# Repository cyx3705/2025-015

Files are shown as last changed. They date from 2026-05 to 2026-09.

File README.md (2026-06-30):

# 2025-015-弹簧测试机械

> 液压与气动 PLC 综合实训装置，面向机电、自动化专业教学实操设备，用于电 - 气 - 液 - 机械联动 PLC 编程实训教学

## 项目效果图
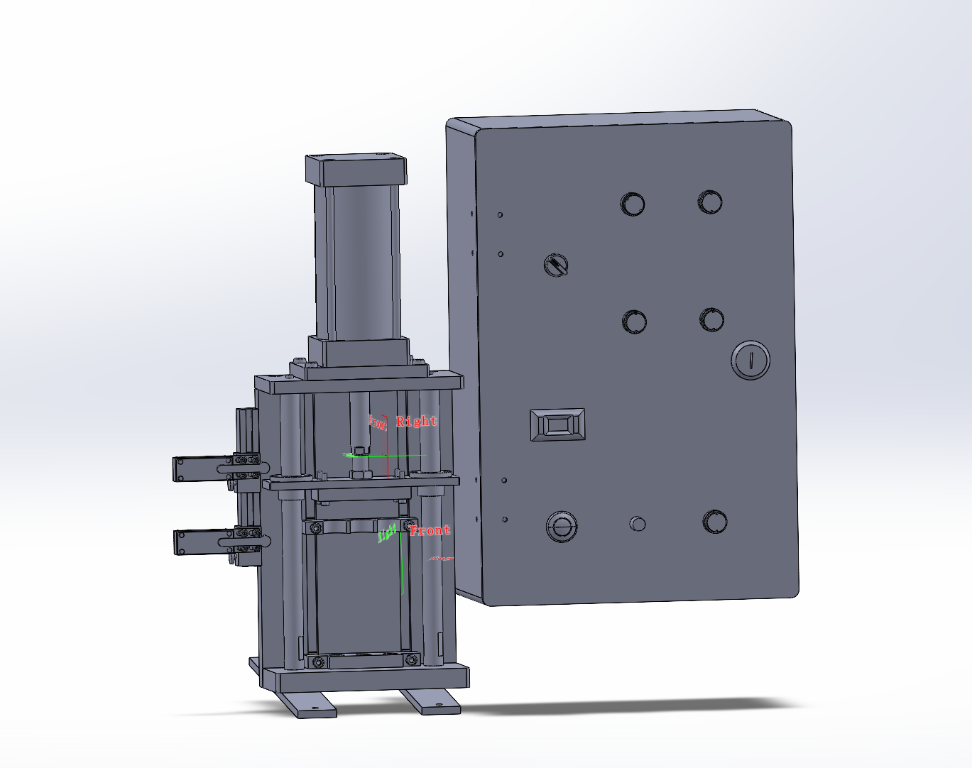
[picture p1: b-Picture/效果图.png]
效果图


## 项目内容

1. **项目定位**
本设备为宁波工程学院机器人学院自研实训设备，是机电、自动化专业入门实操训练平台，依托三菱 PLC 实现气动 / 液压部件动作控制，直观展示电、气、液、机械一体化联动逻辑，作为工业自动化课程配套实践教具。
2. **硬件组成**

- 操作控制面板：急停按钮、上升 / 下降 / 启动 / 停止功能按键、手动 / 自动模式旋钮、电源开关、24V 开关电源；
- 控制核心：三菱 PLC 控制器，负责存储、执行控制逻辑程序；
- 配套电气元件：继电器、端子排、行程传感器、电磁阀执行机构；
- 配套气动液压执行单元：升降气缸、液压气动管路组件。

3. **控制系统说明**

- 硬件接线：外部按钮、急停、行程传感器信号接入 PLC 输入端子，PLC 输出驱动继电器控制气缸升降执行动作；
- 控制逻辑：包含手动单步控制、自动循环升降两套模式，搭配上下限位行程开关实现气缸限位保护；
- 配套资料：完整电气原理图、I/O 梯形图程序、端子接线对照表、整机装配实物图。

4. **实训教学功能**

- 基础实操：电气线路接线、气动液压回路搭建、PLC 硬件接线规范练习；
- 编程实训：三菱梯形图逻辑编写、手动 / 自动模式切换控制、限位互锁程序设计；
- 综合训练：电 - 气联动系统联调、设备故障排查、整机自动化流程调试；
- 课程价值：打通自动化理论与工程实操，掌握元件装配、程序设计、系统联调完整工程流程。

5. **配套文档资源**

- 《液压与气动 PLC 综合实训装置说明书.docx》：整机结构、部件功能、操作规范、实训总结；
- 电气图纸：主回路电气原理图、PLC 控制梯形图、I/O 端子接线对照表；
- 实物素材：控制面板、箱内 PLC 布线、元器件装配实拍图。

## 保留内容
- 本模板项目介绍：此为最初的准备的项目模板
    每个分支项目都会由他去继承
- 作者：Pinavia - 2025

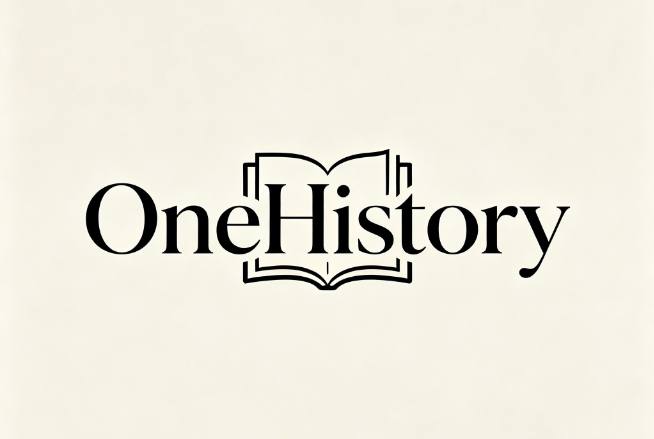
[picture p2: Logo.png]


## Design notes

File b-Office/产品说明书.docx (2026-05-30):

液压与气动 PLC 综合实训装置说明书

一、设备定位：

这是专为机电、自动化专业新手设计的实操训练设备，能帮你从 “看不懂机器” 到 “亲手指挥机器干活”—— 通过 PLC 编程控制气动 / 液压部件动作，直观理解 “电 - 气 - 液- 机械” 的联动逻辑，是工业自动化学习的 “入门实践工具”。控制装置外装如下图

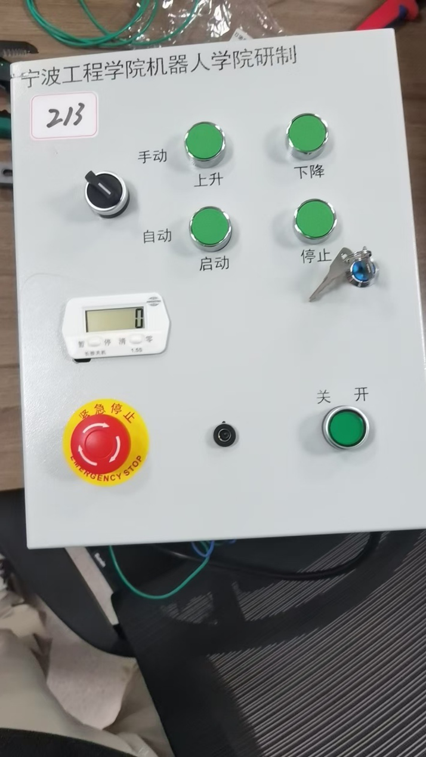
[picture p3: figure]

二、设备部件全解以及原理基础

（一）控制单元（设备左侧：“大脑+控制中枢”）

名称 | 外观 | 功能 | 如何操作
急停按钮 | 箱体外部红色旋转按钮，最为显眼 | 紧急停止所有动作，设备断电 | 按下去后需顺时针旋转复位
功能按钮 | 箱体外部上方绿色小按钮（急停旁） | 手动发送 “上升/ 下降 / 自动/停止” 指令 | 按动时轻按，避免用力过猛损坏
三菱 PLC 控制器 | 箱体内部中间 | 设备 “大脑”，存储 / 执行你的控制程序 | 编程前需连接电脑，禁止带电拔线
开关电源 | 箱体外部右下方 | 输出 24V 安全电压，给电气部件供电 | 控制执行单位的电源

（二）控制部件电气原理图如下

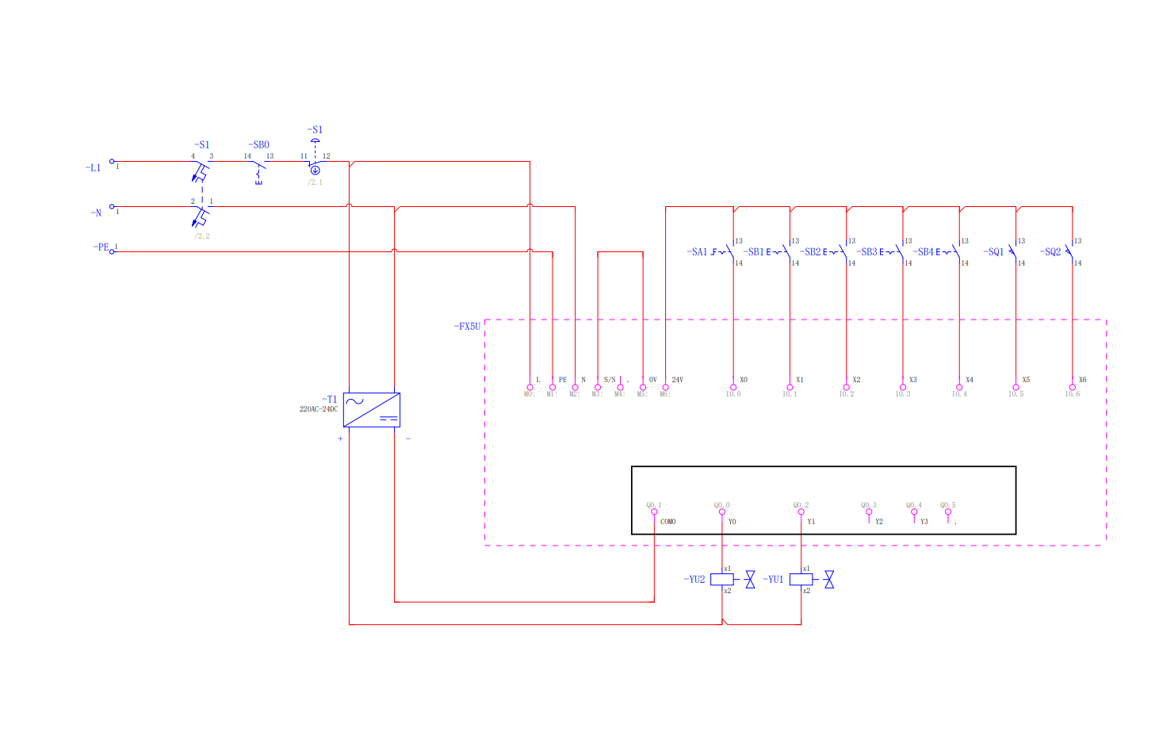
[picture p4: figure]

其中S1为主闸，SA1为急停开关，SB1,SB2,SB3,SB4为功能按钮。当左侧的急停、按钮、传感器等元件动作时，信号通过端子排传到 - P130 - 模块的输入口；模块根据程序判断后，从输出口发出信号，驱动右侧的继电器 / 接触器，最终控制设备的运行、停止等动作。以下为梯形图

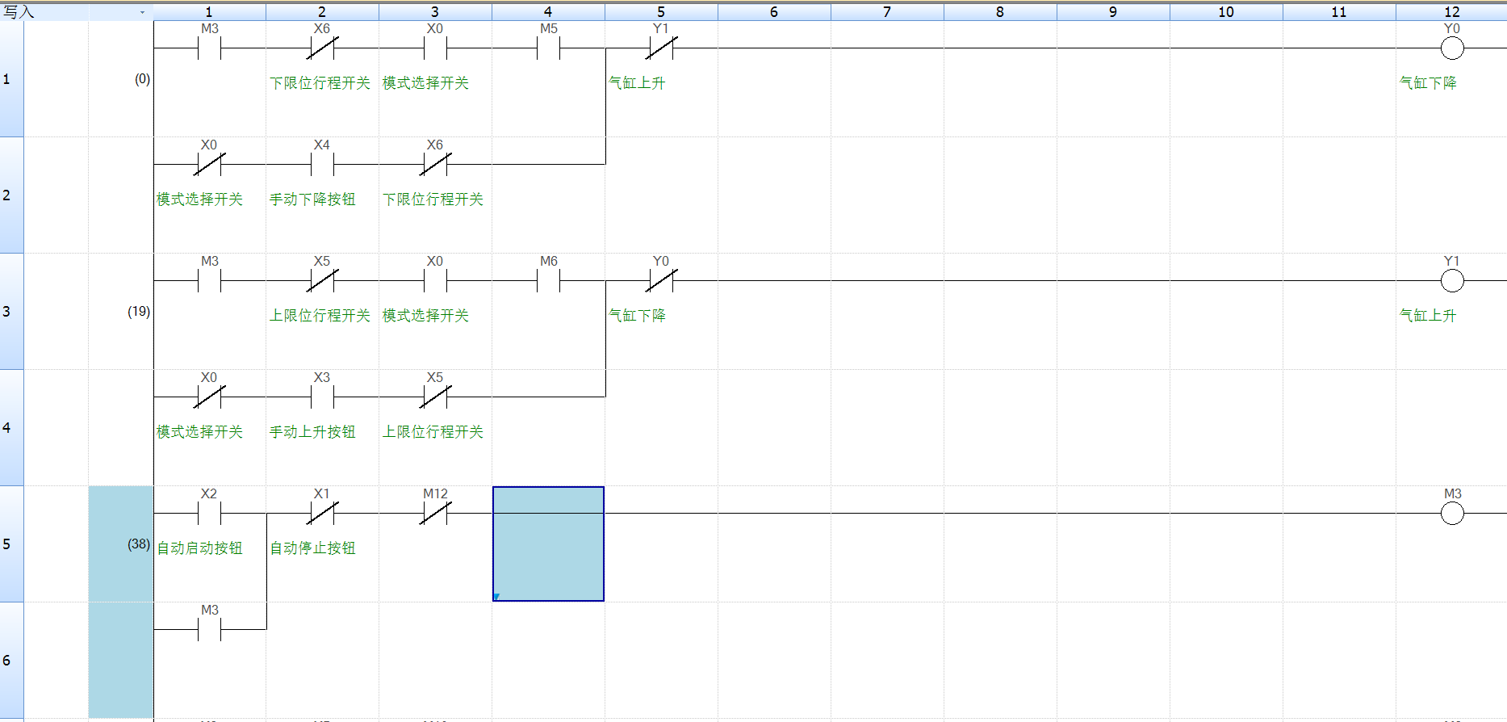
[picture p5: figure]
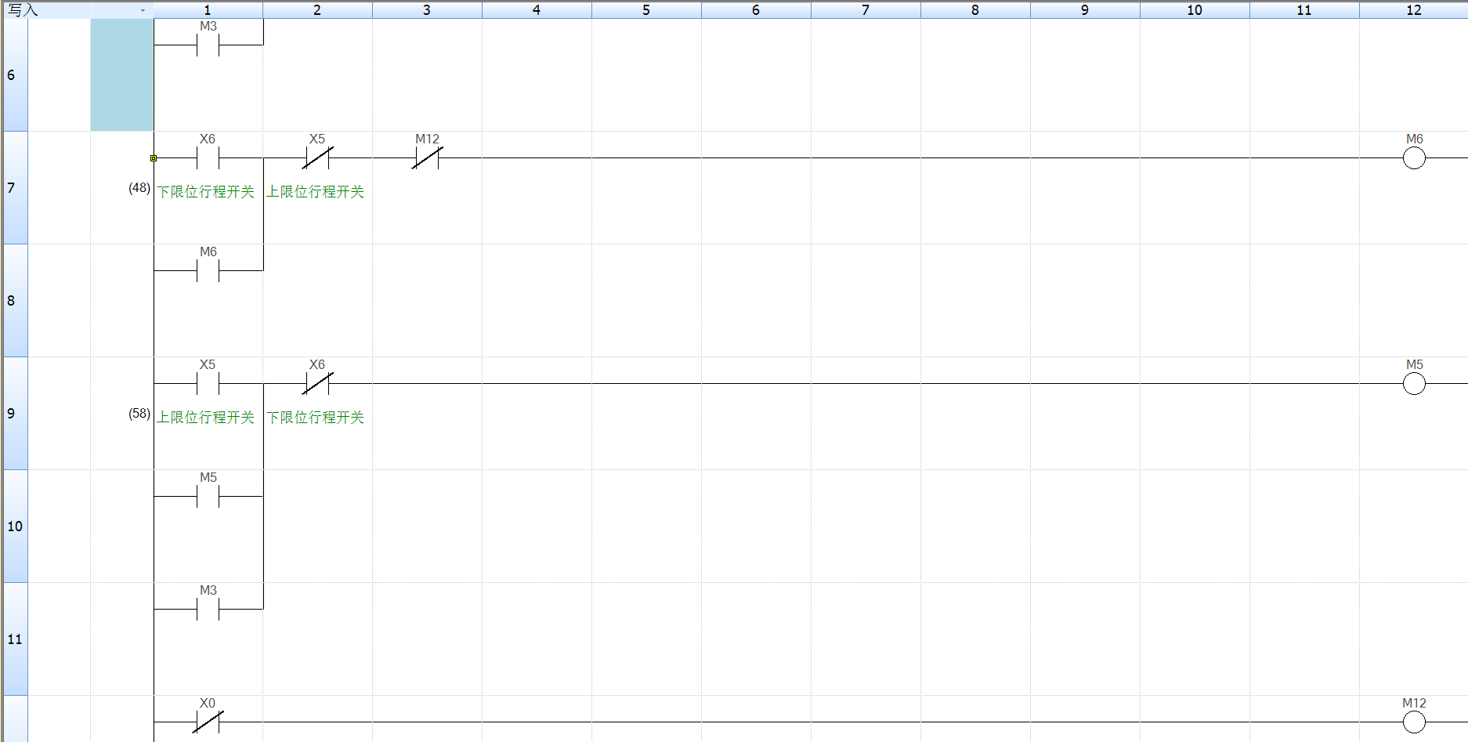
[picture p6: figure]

1控制部分的梯形图

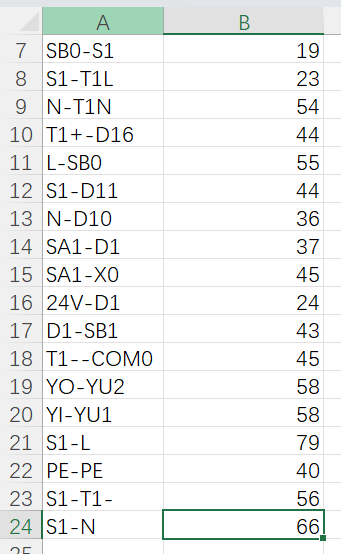
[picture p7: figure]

以下为详细接线表

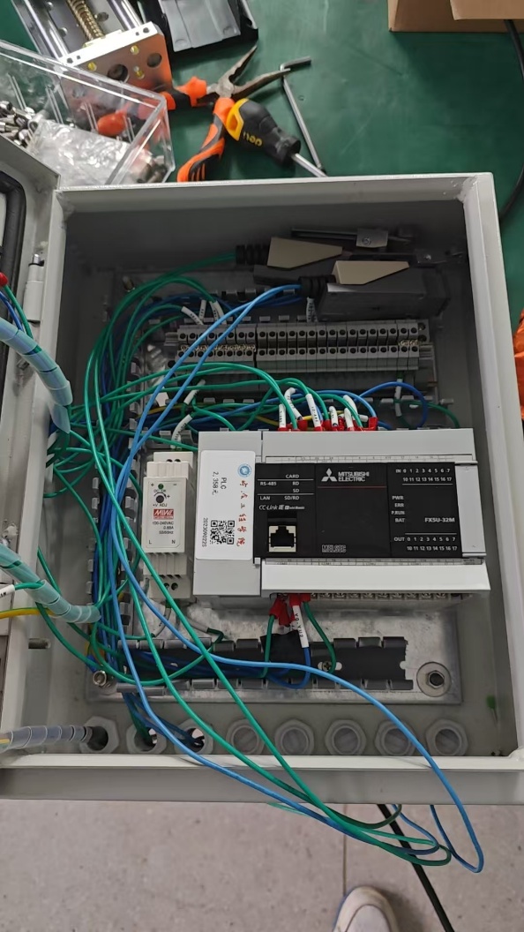
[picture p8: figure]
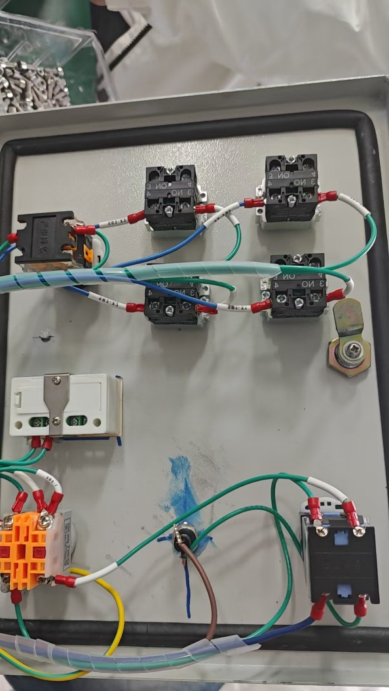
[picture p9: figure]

（三）最后的总装实物图

三、课程小结

本次液压与气动PLC综合实训，以实操为核心载体，有效打通了理论与工程应用的衔接。通过实训装置的实操演练，不仅夯实了专业基础，将分散的液压气动元件知识、PLC编程逻辑深度融合，清晰掌握了回路搭建、程序设计与系统联动的完整流程，更实现了从理论学习者到动手实践者的转变。

实训中，熟练掌握了元件组装、管路连接、PLC编程及常见故障排查等核心技能，同时培养了工程化思维与规范操作意识。此次实训不仅提升了专业实操能力，更构建起完整的知识应用体系，为后续专业学习和工程实践奠定了坚实基础。

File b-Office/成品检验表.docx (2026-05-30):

产品名称： 生产批次 ：

型号规格： 检验日期： 年 月 日

生产单位： 检验人员：

检验类型 □ 出厂检验 □ 型式检验 □ 复检 □ 其他：______ 抽样数量 （全检填 “全检”）

序号 | 检验项目 | 检验要求 | 检验方法 | 检验工具 | 检验结果（合格/不合格/无此项） | 备注
1 | 外观及安装检查 | 1. 设备整体无变形、破损，表面无明显划痕、污渍；2. 各元器件（气缸、电磁阀、行程开关、按钮、保险盒、PLC等）安装牢固、位置准确，固定螺栓无松动；3. 线路布置规整，绑扎牢固，标识清晰，无交叉缠绕、破损裸露现象；4. 气管连接密封良好，无松动、老化迹象 | 目视检查设备外观，手动检查元器件固定情况，梳理线路和气管布置 | 扳手、螺丝刀（辅助检查螺栓紧固性）
2 | 电气系统基础性能 | 1. 电源适配正常，接入24V直流电源后，设备无短路、漏电现象；2. 保险盒选型合理，保险管规格符合设计要求，能正常起到过载保护作用；3. 各电气元器件接线正确，无接错、虚接情况 | 1. 接入24V电源，用测电工具检测电源输出及设备供电情况；2. 检查保险盒及保险管规格，模拟轻微过载场景验证保护功能；3. 对照电气原理图核查接线准确性 | 万用表、测电笔、电源适配器（24V）
3 | 气动系统性能 | 1. 压缩空气压力稳定在0.6MPa，无泄漏；2. 气缸推力不大于4500N，运行平稳，无卡顿、异常异响；3. 三位五通电磁阀动作灵敏，能准确控制气缸换向 | 1. 接入压缩空气，调节压力至0.6MPa，保持10分钟，观察压力表变化及气管、接口处是否漏气；2. 启动设备使气缸运行，用测力计测量气缸推力；3. 分别控制电磁阀YV1、YV2线圈通电，观察气缸换向是否准确 | 压力表、测力计、肥皂水（检测漏气）
4 | 常规电气控制功能（方案一） | 1. 模式切换正常：通过选择开关切换手动/自动模式，切换后对应模式按钮生效，另一模式按钮失效；2. 手动模式：按下“上升”“下降”按钮，滑块准确动作，松开按钮滑块保持当前位置；3. 自动模式：按下“启动”按钮，滑块下行，触发下限位行程开关（SQ2）后换向上行；触发上限位行程开关（SQ1）后换向下行，实现往复循环；按下“停止”按钮，设备立即停止，滑块保持位置 | 1. 操作模式选择开关，分别在两种模式下测试各控制按钮功能；2. 自动模式下启动设备，观察滑块往复运动及行程开关触发后的换向情况，测试停止按钮功能 | 秒表（辅助观察循环稳定性） | | 无常规电气控制方案时填“无此项”
5 | PLC控制功能（方案二） | 1. 与常规电气控制功能要求一致（模式切换、手动/自动模式动作正常）；2. PLC输入输出信号准确，与I/O地址分配表完全匹配；3. 梯形图程序运行稳定，无程序错误、动作紊乱现象 | 1. 同常规电气控制功能测试方法；2. 用PLC编程软件连接设备，监控输入输出信号状态，对照I/O地址分配表核查；3. 连续运行自动模式30分钟，观察程序运行稳定性 | PLC编程软件、电脑（连接PLC）、秒表 | | 无PLC控制方案时填“无此项”
6 | 行程开关功能 | SQ1（上限位）、SQ2（下限位）安装位置准确，滑块运动至极限位置时能可靠触发，触发后立即控制气缸换向，无延迟、误触发情况 | 启动自动模式，观察滑块运行至上下极限位置时行程开关的触发状态及气缸换向响应；手动推动滑块触碰行程开关，验证触发可靠性 | 直尺（辅助测量行程开关安装位置）
7 | 安全性能 | 1. 设备运行过程中无漏电、异响、过热等安全隐患；2. 停止按钮反应灵敏，紧急情况下能快速切断控制信号，保障设备和人员安全 | 1. 设备连续运行1小时，用红外测温仪检测关键元器件（PLC、电磁阀、电源接口）温度，用测电笔检测设备外壳是否漏电；2. 多次测试停止按钮，验证紧急停止功能 | 红外测温仪、测电笔
8 | 附属资料核查 | 电气原理图（标注电线规格）、电气开线表、BOM清单、产品说明书、PLC梯形图、I/O地址分配表等资料完整、准确，与成品实际情况一致 | 对照成品设备，逐一核查各项附属资料的完整性和准确性 | 相关设计资料（电气原理图、BOM清单等）
9 | 其他专项要求 | 根据项目设计补充的其他技术要求（如运行噪音、循环稳定性等） | 按补充技术要求对应的测试方法执行 | 对应专项测试工具 | | 无专项要求时填“无此项”

检验结论： □ 合格（所有检验项目均符合要求） □ 不合格（存在不符合项，详见备注） □ 整改后合格（不符合项已整改并验证通过）

不合格项整改要求 ：1. 不符合项描述：

2. 整改期限： 年 月 日

3. 整改措施：

整改后检验结果： □ 合格 □ 仍不合格

审核人员签字： 日期： 年 月 日

备注 （其他需要说明的事项）：

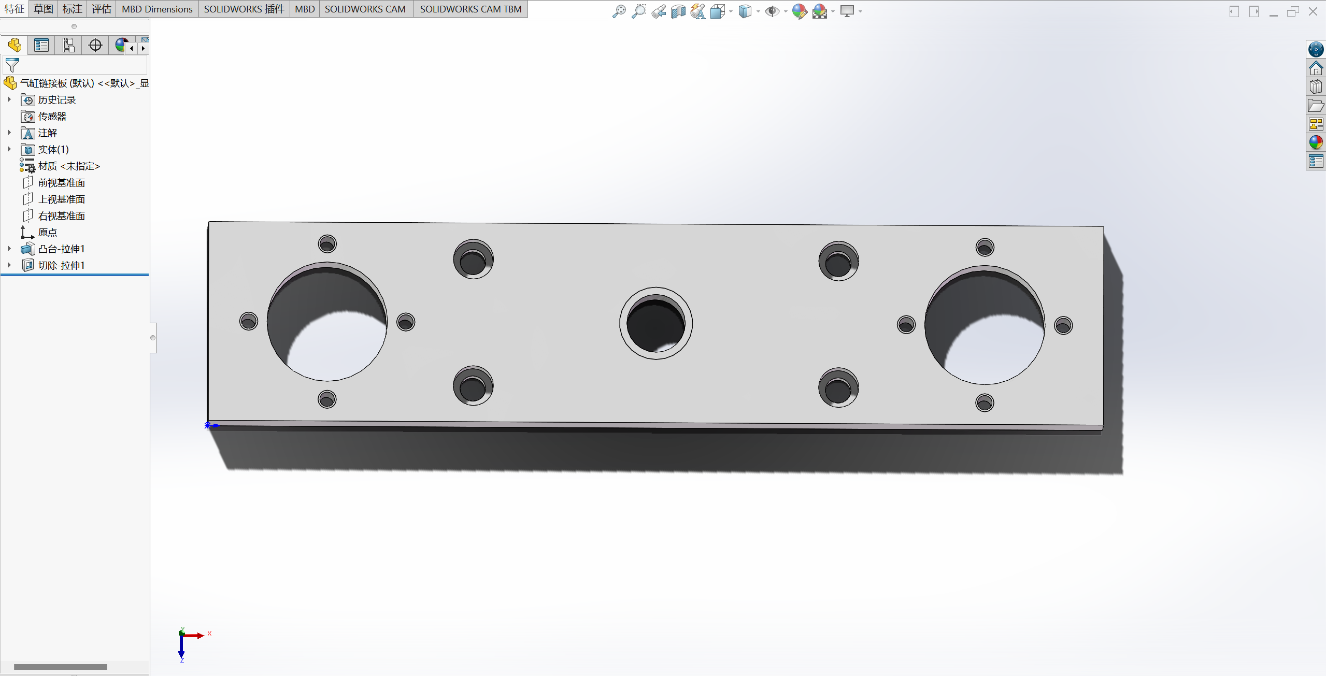
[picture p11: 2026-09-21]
b-Picture/第四次作业图片记录 (1).png

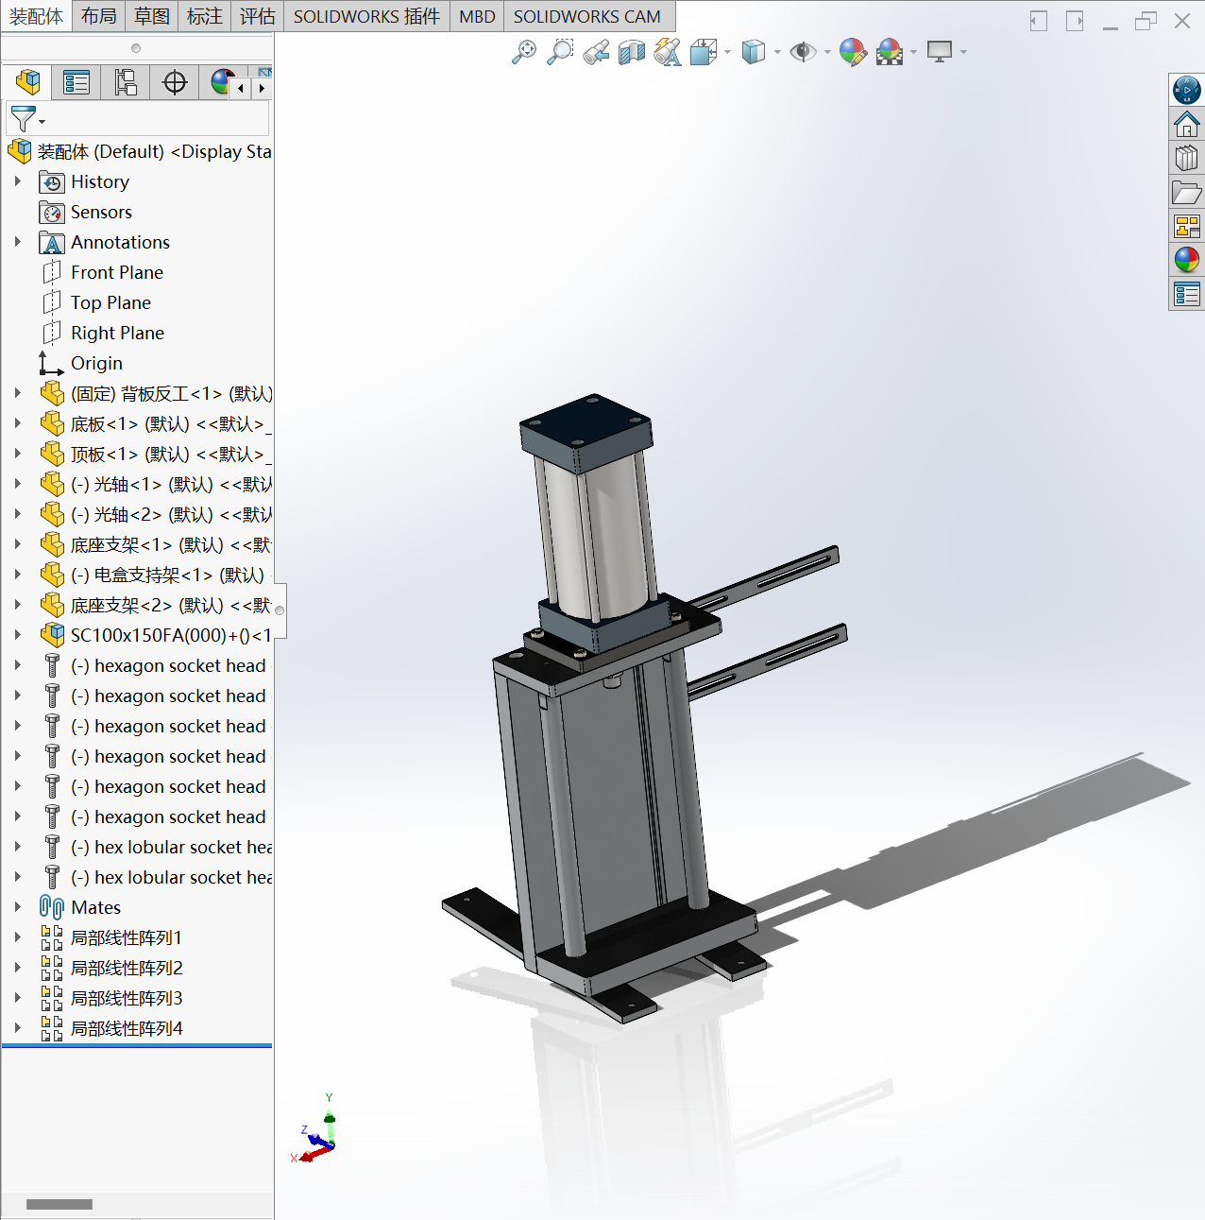
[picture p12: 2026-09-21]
b-Picture/第三次作业图片记录 (6).png

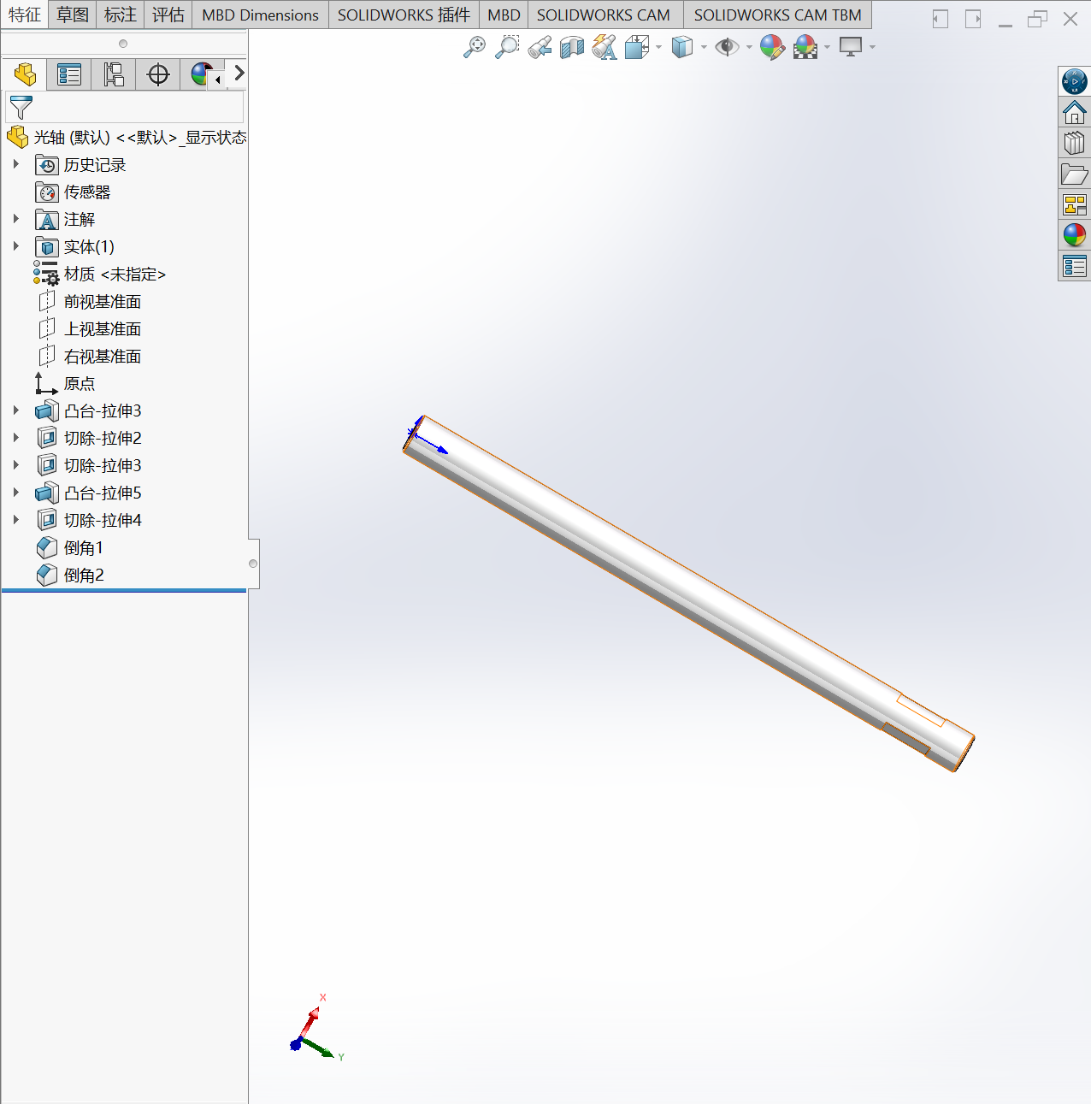
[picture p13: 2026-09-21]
b-Picture/第三次作业图片记录 (3).png

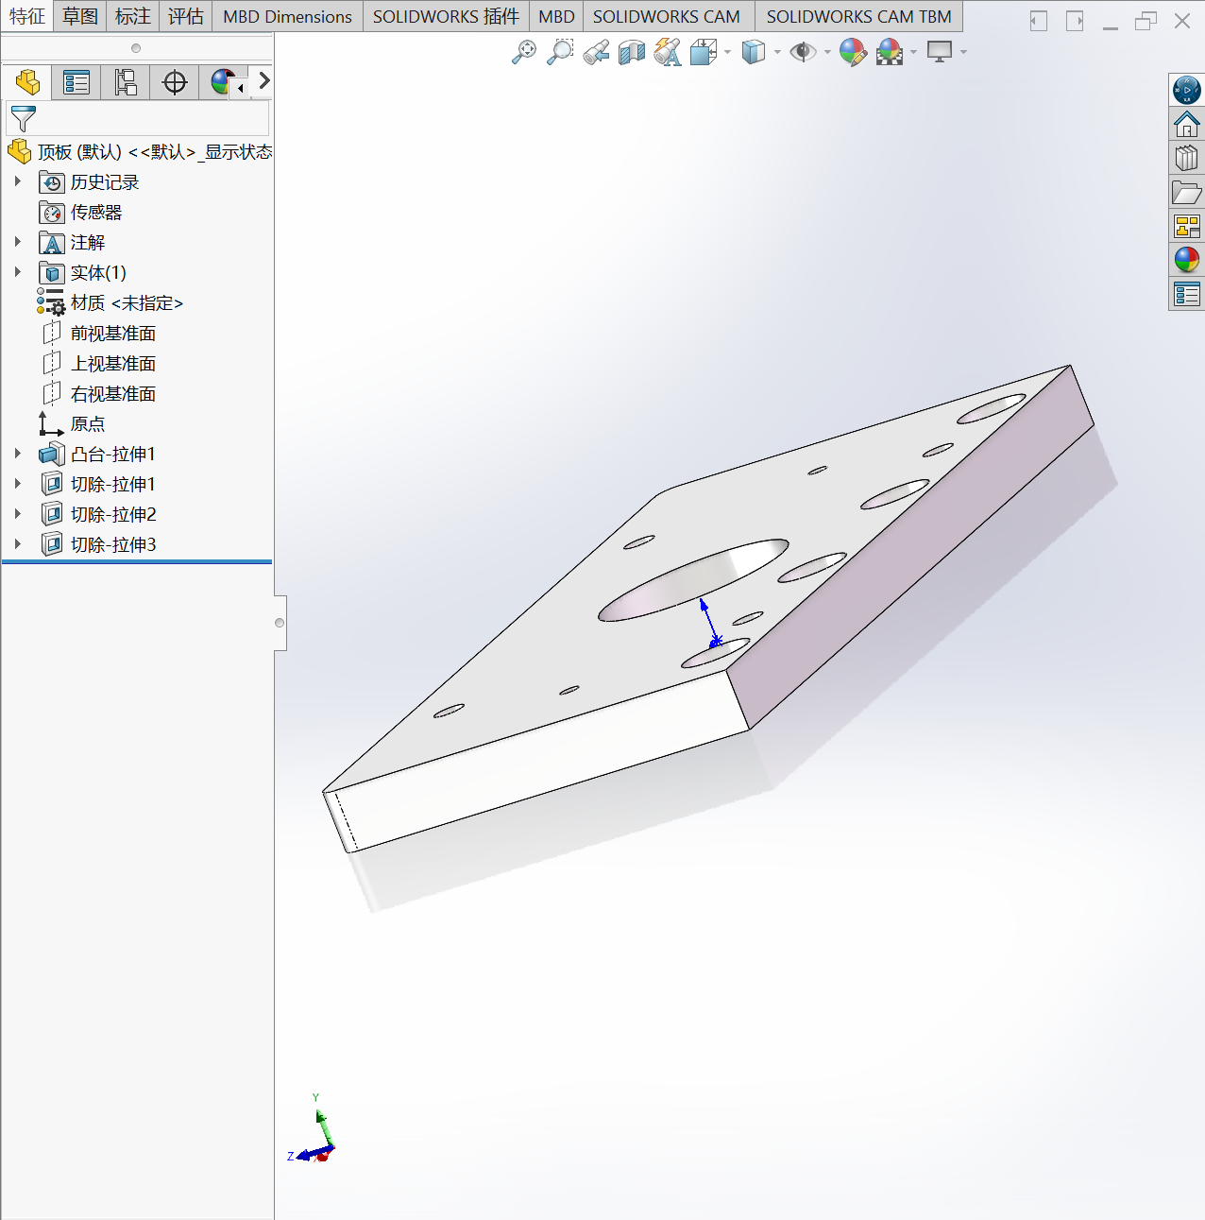
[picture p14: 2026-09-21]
b-Picture/第三次作业图片记录 (5).png

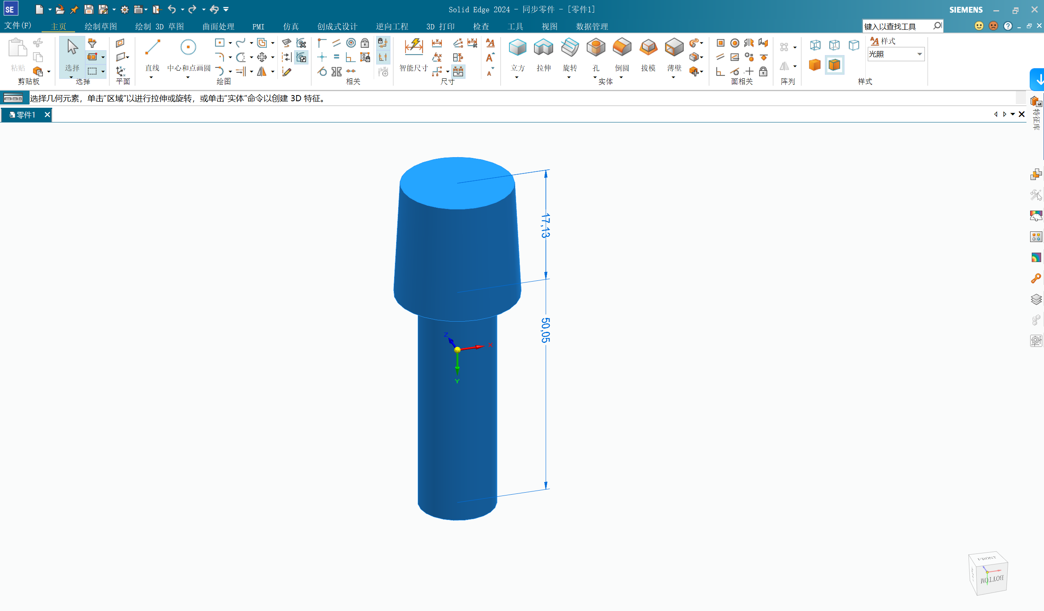
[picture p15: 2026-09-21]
b-Picture/第五次作业图片记录 (3).png

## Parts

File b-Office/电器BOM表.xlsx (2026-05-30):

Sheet: Revision History
Revision 版本 | Description 变更描述 | Date 变更日期 | Updated BY 变更人 | Remarks 备注

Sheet: BOM模板
Item 序号 | 名称 | 型号 | Manufacturer 制造商 | QTY 数量 | Unit 单位 | Remarks 备注
1 | SB1(上升) | NP2-EA31 | 正泰 | 1 | 个 | 绿，常开
2 | SB2(下降) | NP2-EA31 | 正泰 | 1 | 个 | 绿，常开
3 | SB3(启动) | NP2-EA31 | 正泰 | 1 | 个 | 绿，常开
4 | SB4(停止) | NP2-EA31 | 正泰 | 1 | 个 | 绿，常开
5 | 急停开关 | NP2-ES442 | 正泰 | 1 | 个 | 红，常闭
6 | 总开关 | NP2-BW1361 | 正泰 | 1 | 个 | 绿，直接式常开
7 | 旋转开关 | NP2-BD25 | 正泰 | 1 | 个 | 二位置锁定，1常开+1常闭
8 | PLC | FX5U-32M | 三菱电器 | 1 | 个
9 | 开关电源 | DR-15-24 | 明纬 | 1 | 个 | 100-240VAC 0.88A 50/60Hz
10 | 接线端子 | UK2.5B | 冠辰 | 24 | 个 | https://e.tb.cn/h.7W7ifaxQ8hWY1d1?tk=cyXVfFPszRI
11 | 电器导轨 | C45 190mm |  | 2 | 个 | https://e.tb.cn/h.7dVqYi3wGRdT4Fx?tk=GNmafFPAPV5
12 | 线槽 | 25×25×175mm | R.star | 3 | 个
13 | 电磁阀 | 4V330C10A | 亚德客 | 1 | 个 | 三位五通
14 | 行程开关 | D4V-8108SZ-N | OMRON | 2 | 个 | 5A 250VAC 0.4A 125VDC
15
16
17
18
19
20

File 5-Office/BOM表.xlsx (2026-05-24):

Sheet: Revision History
Revision 版本 | Description 变更描述 | Date 变更日期 | Updated BY 变更人 | Remarks 备注

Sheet: BOM模板
 | Product Name 成品名称 |  | DOC. Number 文件编号 |  | Rev. 版本号 |  |  | Updated BY 更新人 |  | Checked BY 审核人 |  | Approved BY 批准人
 |  |  | BOM-503TWM0203 |  | 1.00
 |  |  |  |  |  |  |  | Date 日期 |  | Date 日期 |  | Date 日期
 |  |  | Initial Date 初版日期
Item 序号 | 文档号 | Description 名称 | Specification 参数描述 | Manufacturer 制造商 |  | RoHS 有毒 元素 控制 | QTY 数量 | Unit 单位 | Substitute P/N 替代料P/N | Remarks 备注 | EPDM Auto EPDM自动导出 | Optimized 优选等级 | Unit Price 单价(RMB) | Subtotal 合计(RMB)
 |  |  |  | Model No. 型号 | Brand 品牌
1
2
3
4
5
6
7
8
9
10
11
12
13
14
15
16
17
18
19
20
 |  |  |  |  |  |  |  |  |  |  |  |  |  | Total:

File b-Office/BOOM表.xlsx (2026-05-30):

序号 | 名称 | 规格型号 | 数量 | 备注
1 | 保险丝座 |  | 1 | 无
2 | 背板反工 |  | 1
3 | 触碰开关 |  | 2
4 | 触碰开关盒 |  | 4
5 | 导轨 |  | 1
6 | 底板 |  | 1
7 | 底座支架 |  | 1
8 | 电盒支持架 |  | 1
9 | 顶板 |  | 1
10 | 刚体固定架 |  | 1
12 | 工作版 |  | 1
13 | 光轴 |  | 2
14 | 滑块 |  | 2
15 | 计数器 |  | 1
16 | 紧固螺钉 |  | 2
17 | 螺母 |  | 1
18 | 气弹簧固定版 |  | 1
19 | 气缸链接板 |  | 1
20 | 三联支架 |  | 1
21 | 锁芯 |  | 1
22 | 梯形螺母 |  | 4
23 | 铜套 |  | 2
24 | 箱盖 |  | 1
25 | 箱体 |  | 1
26 | 行程开关安专板 |  | 1
27 | 电磁阀 | 4V330C08A | 1
28 | 气缸 | SC100X150 | 1
29 | 内六角螺钉1 | M5X10 | 4
30 | 十字槽螺钉 | M3X16 | 8
31 | 内六角螺钉2 | M6X25 | 8
32 | 内六角螺钉3 | M6X10 | 8
33 | 内六角螺钉4 | M3X30 | 2
34 | 内六角螺钉5 | M8X45 | 4
35 | 内六角螺钉6 | M4X12 | 8
36 | 内六角螺钉7 | M6X35 | 4
37 | 螺母 | M6 | 4
38 | 内六角螺钉7 | M6X20 | 2
39 | 内六角螺钉8 | M6X10 | 2

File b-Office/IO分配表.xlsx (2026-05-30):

列1 | 列2 | 列3 | 列4
类型 | 元件 | 功能 | PLC地址
输入 | SA | 手动/自动选择开关（手动档） | X0
输入 | SB1 | 自动停止按钮（常开） | X1
输入 | SB2 | 自动启动按钮（常开） | X2
输入 | SB3 | 手动上升按钮（常开） | X3
输入 | SB4 | 手动下降按钮（常开） | X4
输入 | SQ1 | 上限位行程开关（常开） | X5
输入 | SQ2 | 下限位行程开关（常开） | X6
输出 | YV1 | 电磁阀线圈1，通电时气缸活塞下降 | Y0（经中间继电器KA1驱动）
输出 | YV2 | 电磁阀线圈2，通电时气缸活塞上升 | Y1（经中间继电器KA2驱动）

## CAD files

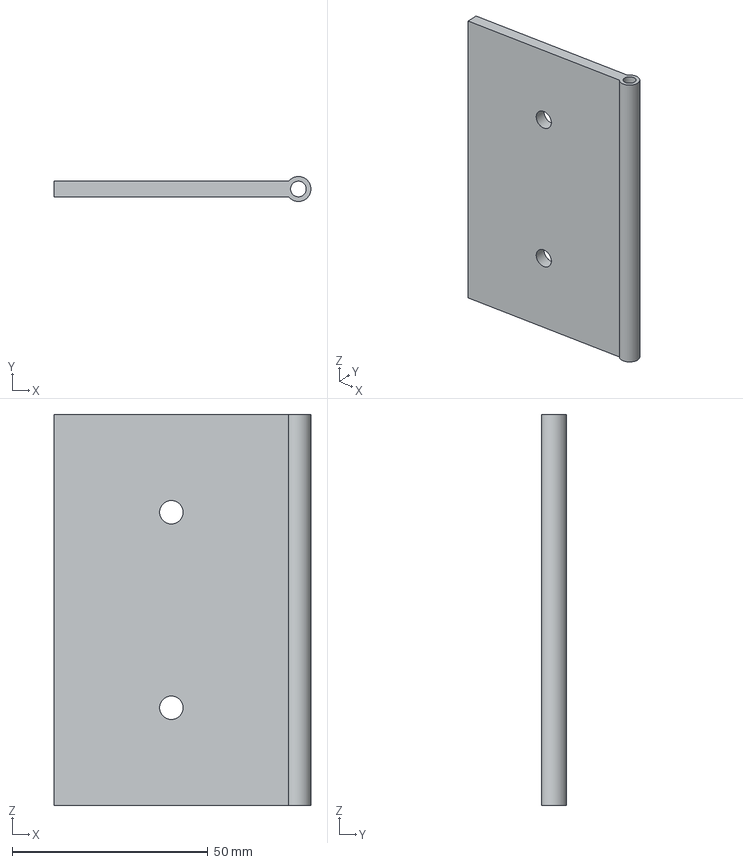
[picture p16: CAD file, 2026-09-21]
b-Module-GE/专配体/heye.stp
65.7 x 6.40 x 100.0 mm

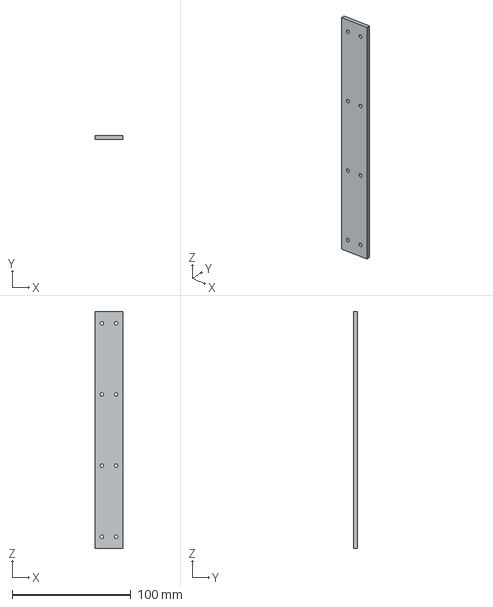
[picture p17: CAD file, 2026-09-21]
b-Module-GE/主体/右侧连接.stp
24.0 x 3.00 x 200.0 mm

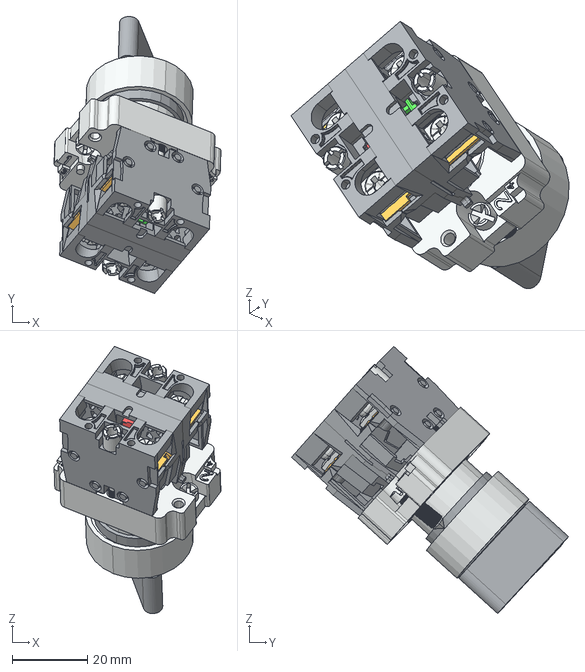
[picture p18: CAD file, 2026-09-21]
b-Module-GE/按钮/NP2-BD按钮三维模型202204.stp
44.4 x 73.7 x 71.1 mm

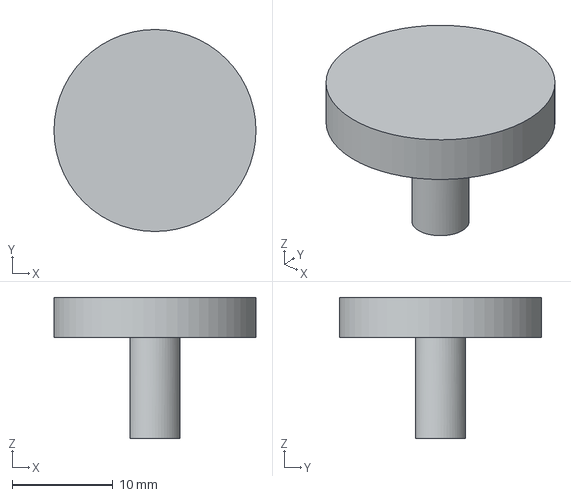
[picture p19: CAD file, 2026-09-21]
b-Module-GE/紧固螺钉.stp
20.0 x 20.0 x 14.0 mm

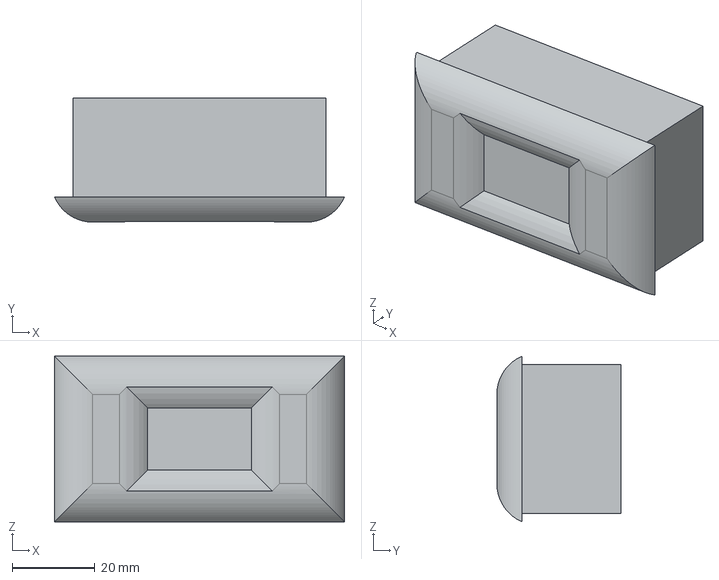
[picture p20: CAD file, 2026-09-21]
b-Module-GE/配件箱/计数器.stp
70.0 x 30.0 x 40.0 mm

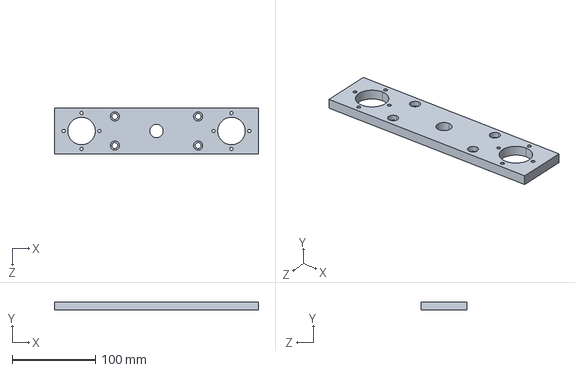
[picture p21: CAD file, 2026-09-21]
b-Module-GE/专配体/气缸链接板.STEP
245.0 x 10.0 x 55.0 mm

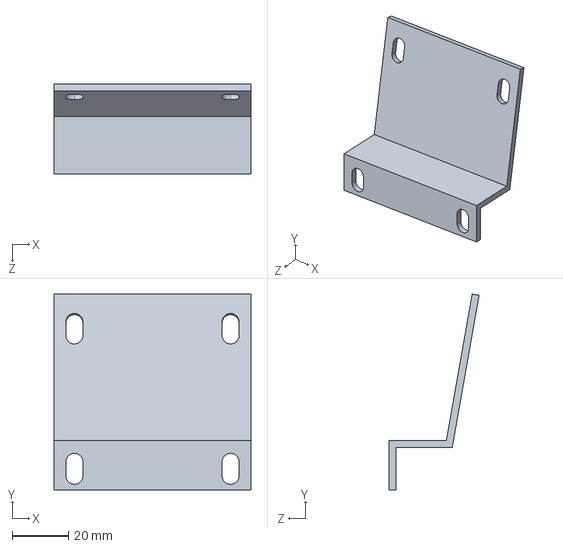
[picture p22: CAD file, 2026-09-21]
b-Module-GE/主体/三联支架.STEP
70.0 x 69.6 x 32.1 mm

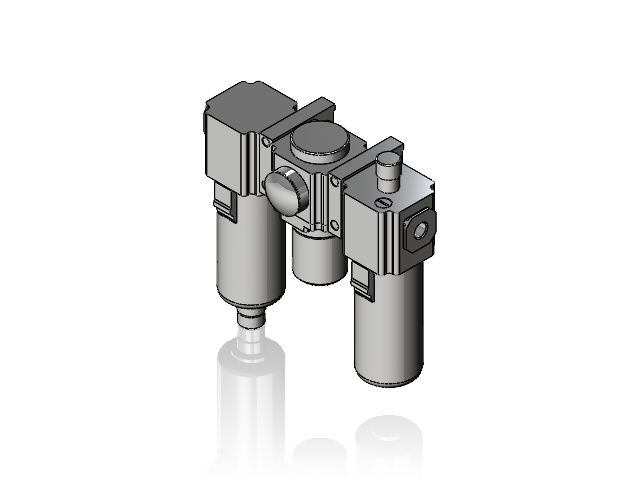
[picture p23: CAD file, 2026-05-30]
b-Module-SW/主体/气缸.SLDASM
GAF30008J
GA300L-P1 x 2
GAR30008SJ
GAL30008J

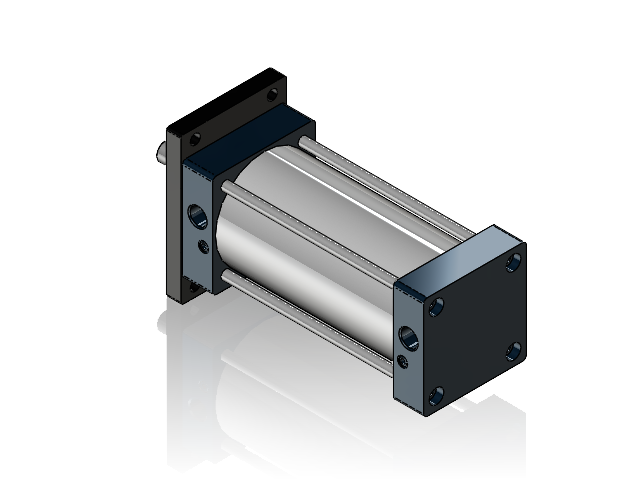
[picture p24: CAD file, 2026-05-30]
b-Module-SW/装配件/气缸/SC100x150FA(000)+()_1.sldasm
SC100X150_c
SC-100x150-FA(0)_r
SC-100-M20x1.5 - Nut
F-SC100FA(SC)
SC-100 Screw x 4

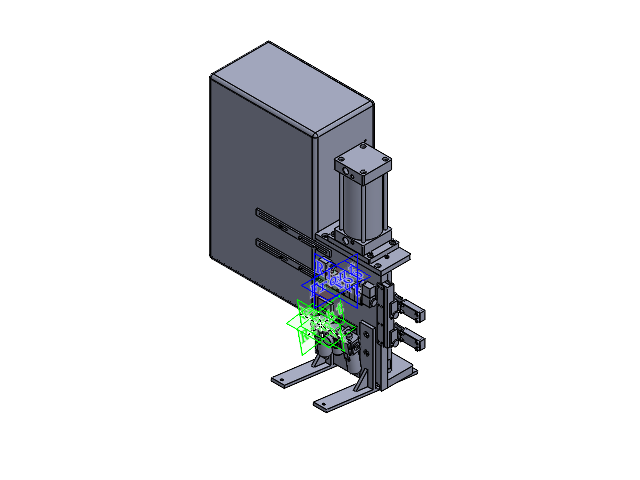
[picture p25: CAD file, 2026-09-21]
b-Module-SW/装配体2.SLDASM
背板反工
底板
顶板
光轴 x 2
底座支架 x 2
电盒支持架 x 2
hexagon socket head cap screws gb x 42
hex lobular socket head cap screws-4.8 gb x 6
行程开关安专板 x 2
箱体1
箱盖1
np2-bd按钮三维模型202204
np2-bw1按钮三维模型202204 x 5
np2-bw4按钮三维模型202204
锁芯
计数器
保险丝座
SC100X150_c
SC-100x150-FA(0)_r
F-SC100FA(SC)
螺母
lianjie
气弹簧固定版
刚体固定架
工作版
气缸链接板
铜套 x 2
梯形螺母 x 4
导轨
滑块 x 2
紧固螺钉 x 2
触碰开关盒 x 2
触碰开关.stp x 2
三联支架
4V330C-08-Valve_Body
cross recessed cheese head screws gb x 8
hex lobular socket head cap screws-8.8 gb x 12
hex nuts, style 1-grades ab gb x 4
GAF20006J
GA200L-P1 x 2
GAR20006SJ
GAL20006J

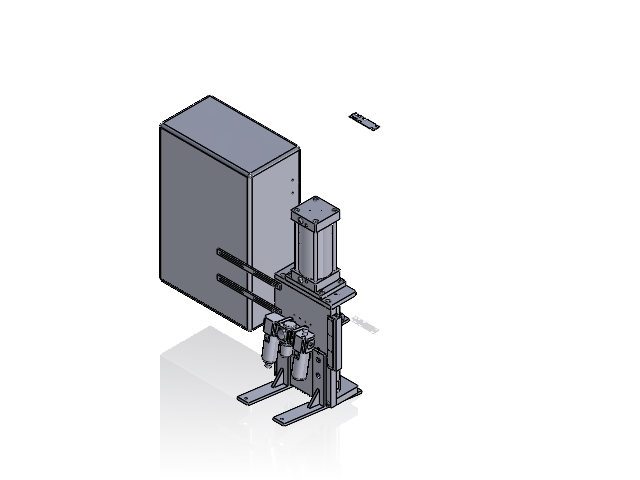
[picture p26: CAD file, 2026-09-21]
b-Module-SW/装配体.SLDASM
背板反工
底板
顶板
光轴 x 2
底座支架 x 2
电盒支持架 x 2
hexagon socket head cap screws gb x 11
hex lobular socket head cap screws-4.8 gb x 6
三联支架
行程开关安专板
箱体1
箱盖1
np2-bd按钮三维模型202204
np2-bw1按钮三维模型202204 x 5
np2-bw4按钮三维模型202204
锁芯
计数器
保险丝座
GAF30008J
GA300L-P1 x 2
GAR30008SJ
GAL30008J
SC100X150_c
SC-100x150-FA(0)_r
F-SC100FA(SC)
螺母
lianjie
气弹簧固定版
刚体固定架
工作版
气缸链接板
铜套 x 2
梯形螺母 x 4
导轨

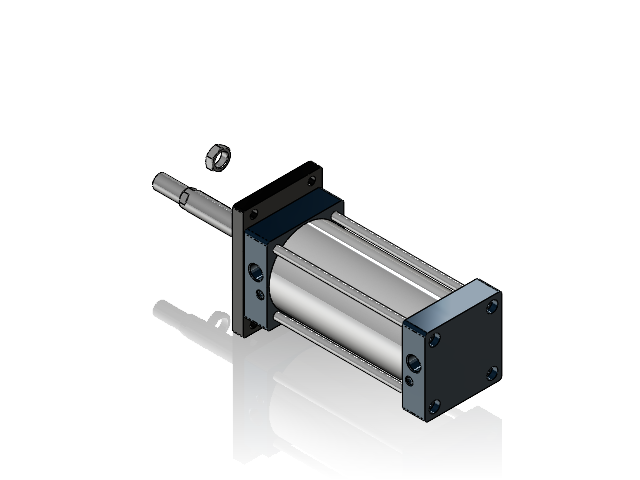
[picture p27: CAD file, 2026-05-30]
b-Module-SW/装配件/气缸/SC100x150FA(000)+().sldasm
SC100X150_c
SC-100x150-FA(0)_r
SC-100-M20x1.5 - Nut
F-SC100FA(SC)
SC-100 Screw x 4

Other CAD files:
2-Module-SW/0-装配体.SLDASM
b-Module-SW/装配件/气动阀门连接件/4V330C10B.sldasm
b-Module-SW/装配件/气动阀门连接件/4V330C08A.sldasm
4-Module-2D/工程图.dwg
b-Module-2D/电器布局图.dwg
b-Module-SW/np2-bd按钮三维模型202204.SLDPRT
b-Module-2D/三联支架.SLDDRW
b-Module-2D/光轴.SLDDRW
b-Module-2D/刚体固定架.SLDDRW
b-Module-2D/工作版.SLDDRW
b-Module-2D/底座支架.SLDDRW
b-Module-2D/底板.SLDDRW
b-Module-2D/气弹簧固定版.SLDDRW
b-Module-2D/气缸链接板.SLDDRW
b-Module-2D/电盒支持架.SLDDRW
b-Module-2D/背板反工.SLDDRW
b-Module-2D/行程开关安专板.SLDDRW
b-Module-2D/装配体2.SLDDRW
b-Module-2D/顶板.SLDDRW
b-Module-GE/GAC30008S.STEP
b-Module-GE/专配体/NP2-BW1按钮三维模型202204.stp
b-Module-GE/专配体/NP2-BW4按钮三维模型202204.stp
b-Module-GE/专配体/保险丝座.stp
b-Module-GE/专配体/光轴.STEP
b-Module-GE/专配体/刚体固定架.stp
b-Module-GE/专配体/工作版.stp
b-Module-GE/专配体/底座支架.STEP
b-Module-GE/专配体/气弹簧固定版.stp
b-Module-GE/专配体/电盒支持架.STEP
b-Module-GE/专配体/箱体.stp
b-Module-GE/专配体/箱盖.stp
b-Module-GE/专配体/背板反工.STEP
b-Module-GE/专配体/行程开关安专板.STEP
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

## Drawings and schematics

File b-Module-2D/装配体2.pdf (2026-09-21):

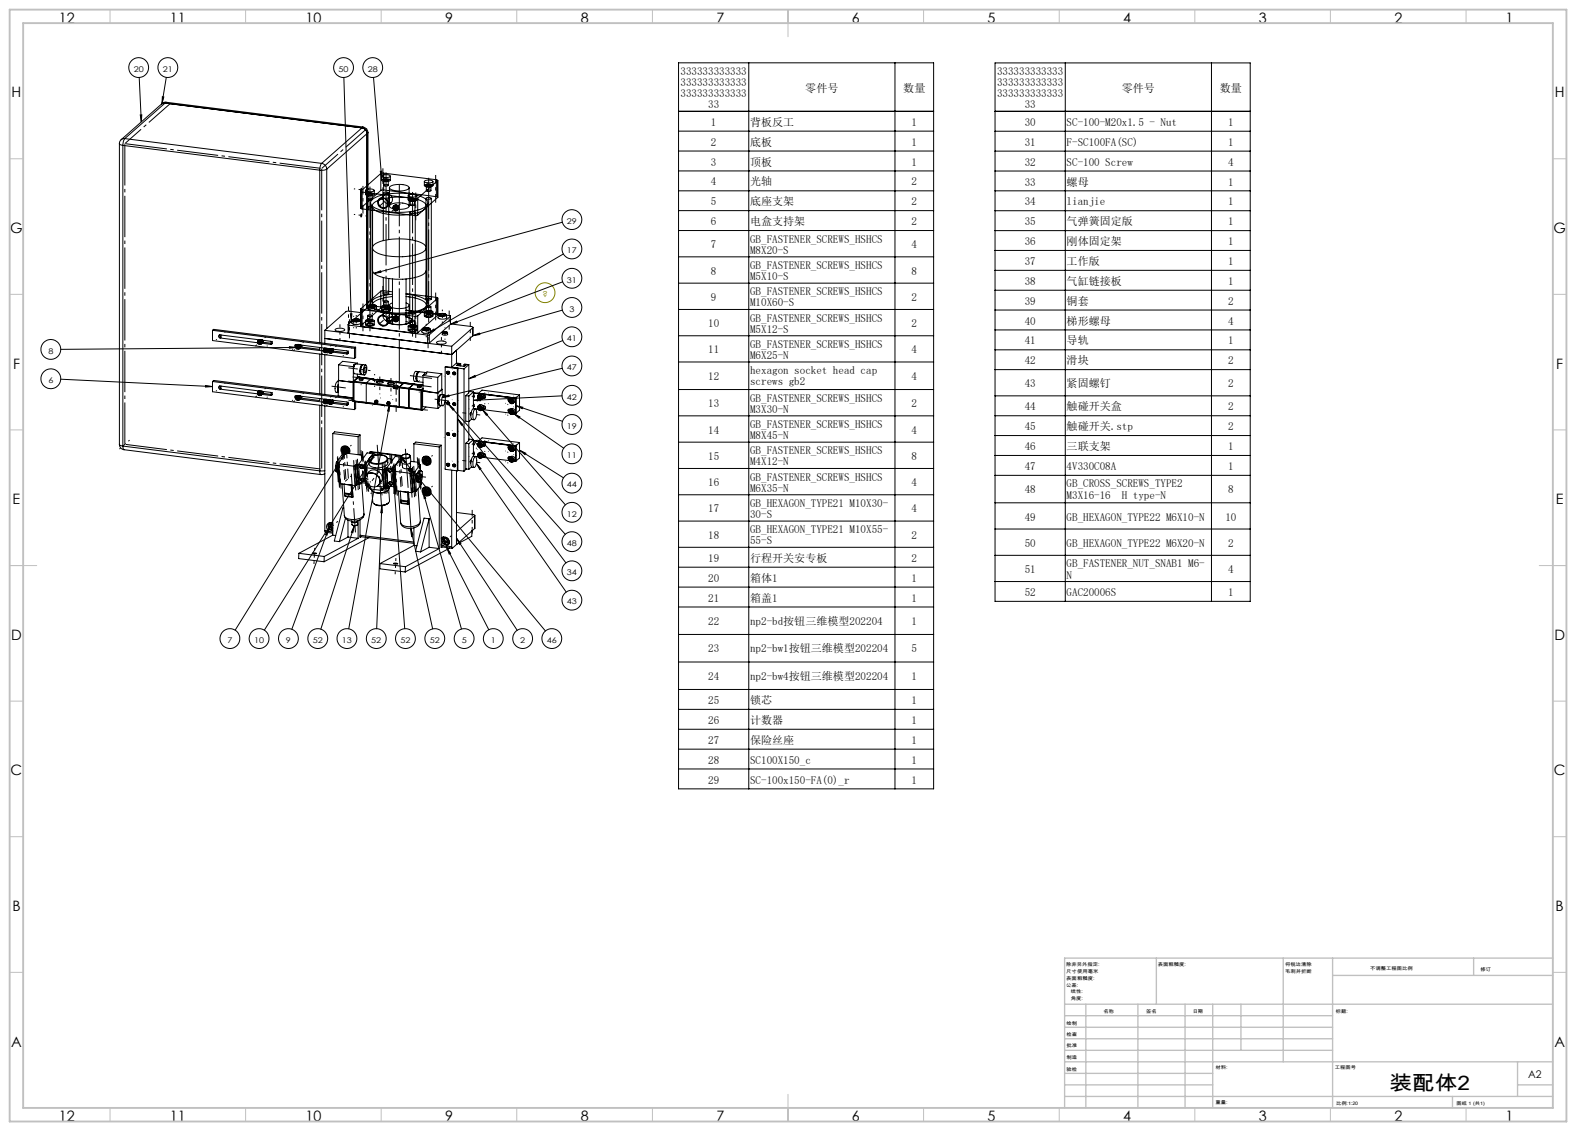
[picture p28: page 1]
hexagon socket head cap; screws gb2; GB_HEXAGON_TYPE21 M10X30-; GB_HEXAGON_TYPE21 M10X55-; SC-100-M20x1.5 - Nut; SC-100 Screw; M3X16-16 H type-N; GB_HEXAGON_TYPE22 M6X10-N; GB_HEXAGON_TYPE22 M6X20-N; GB_FASTENER_NUT_SNAB1 M6- N

除非另外指定: 尺寸使用毫米 表面粗糙度: 公差: 线性: 角度: | 表面粗糙度: | 将锐边清除 毛刺并折断 | 不调整工程图比例 | 修订

绘制
检查
批准
制造
验检 | | | | 材料: | 工程图号 装配体2 | A2

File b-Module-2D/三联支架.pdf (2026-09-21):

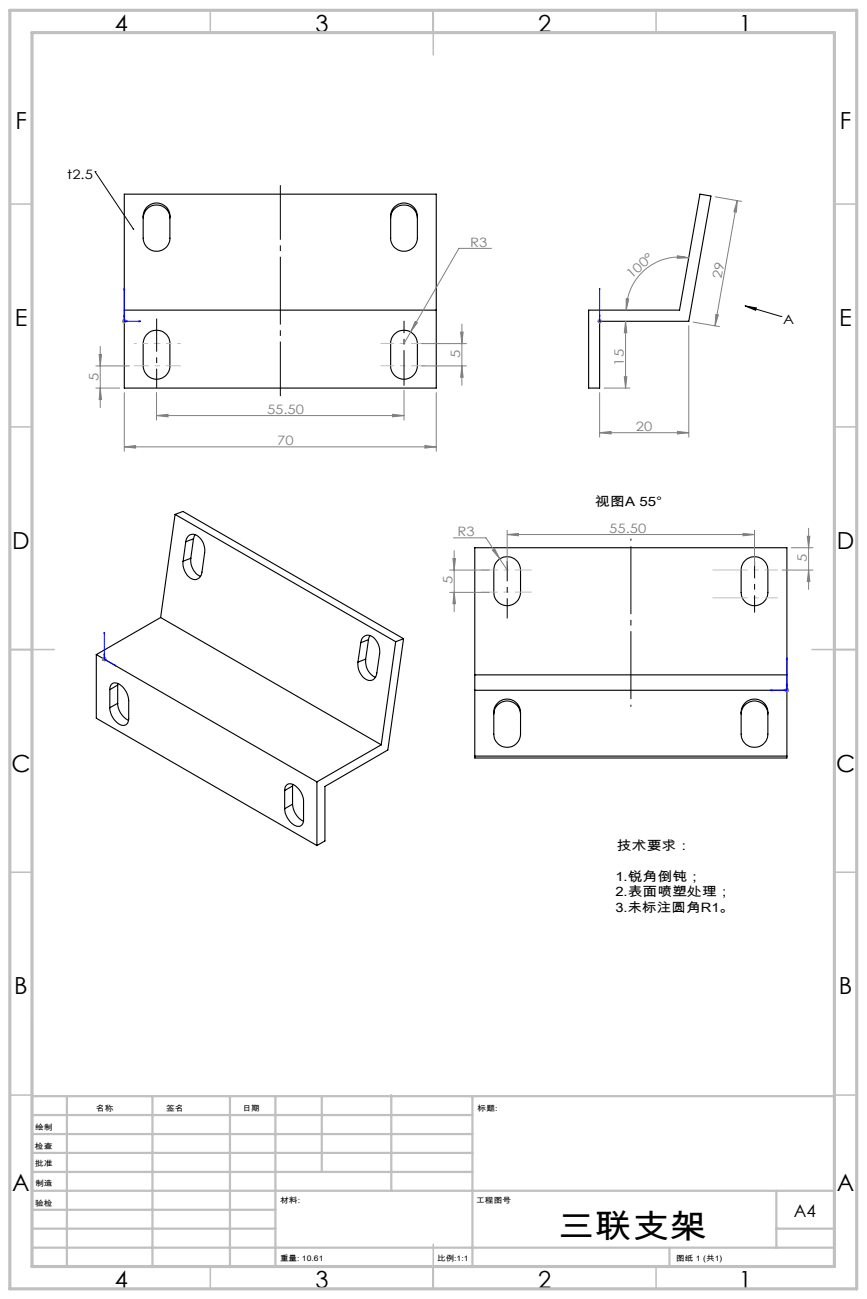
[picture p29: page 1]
视图A 55°

绘制
检查
批准
制造
验检 | | | | 材料: | 工程图号 三联支架 | A4

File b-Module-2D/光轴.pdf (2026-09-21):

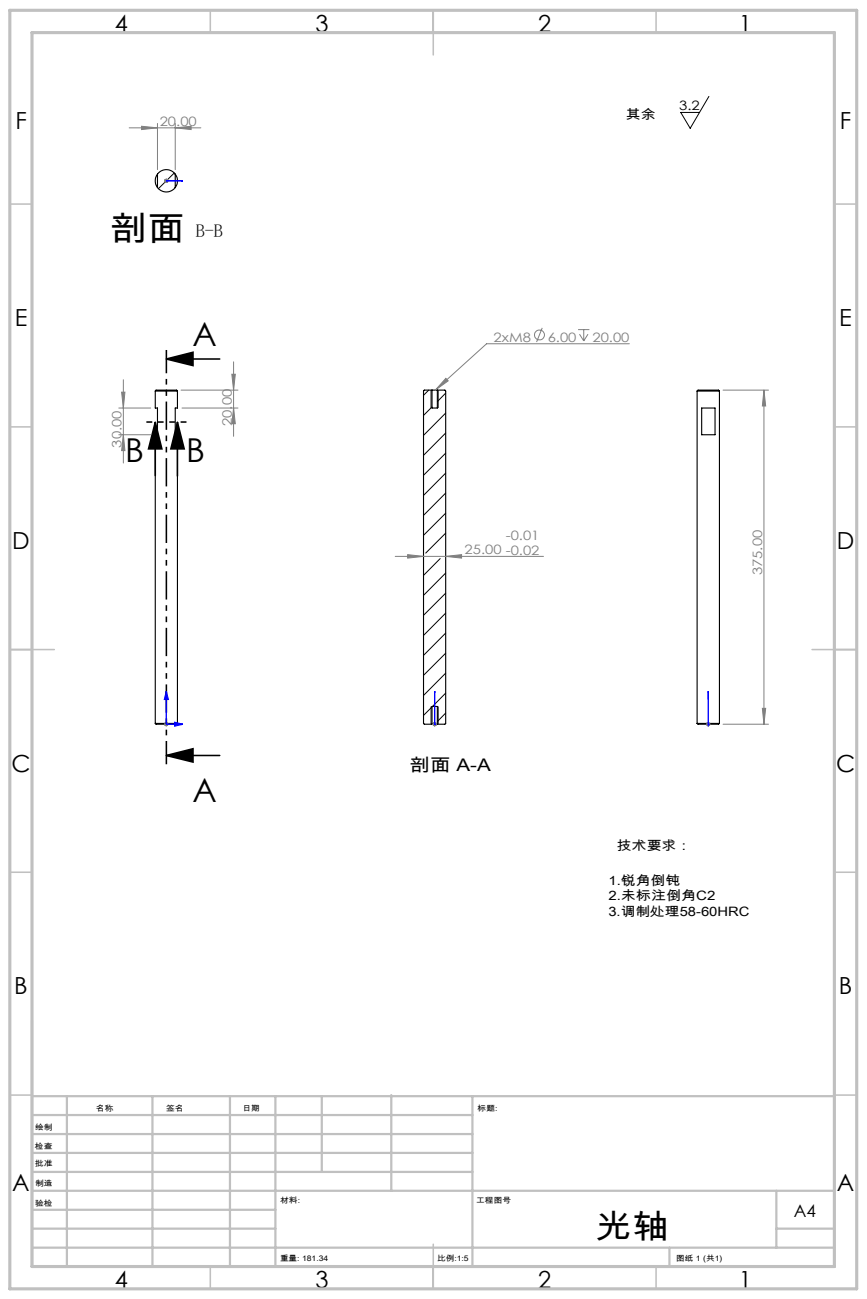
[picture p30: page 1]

绘制
检查
批准
制造
验检 | | | | 材料: | 工程图号 光轴 | A4

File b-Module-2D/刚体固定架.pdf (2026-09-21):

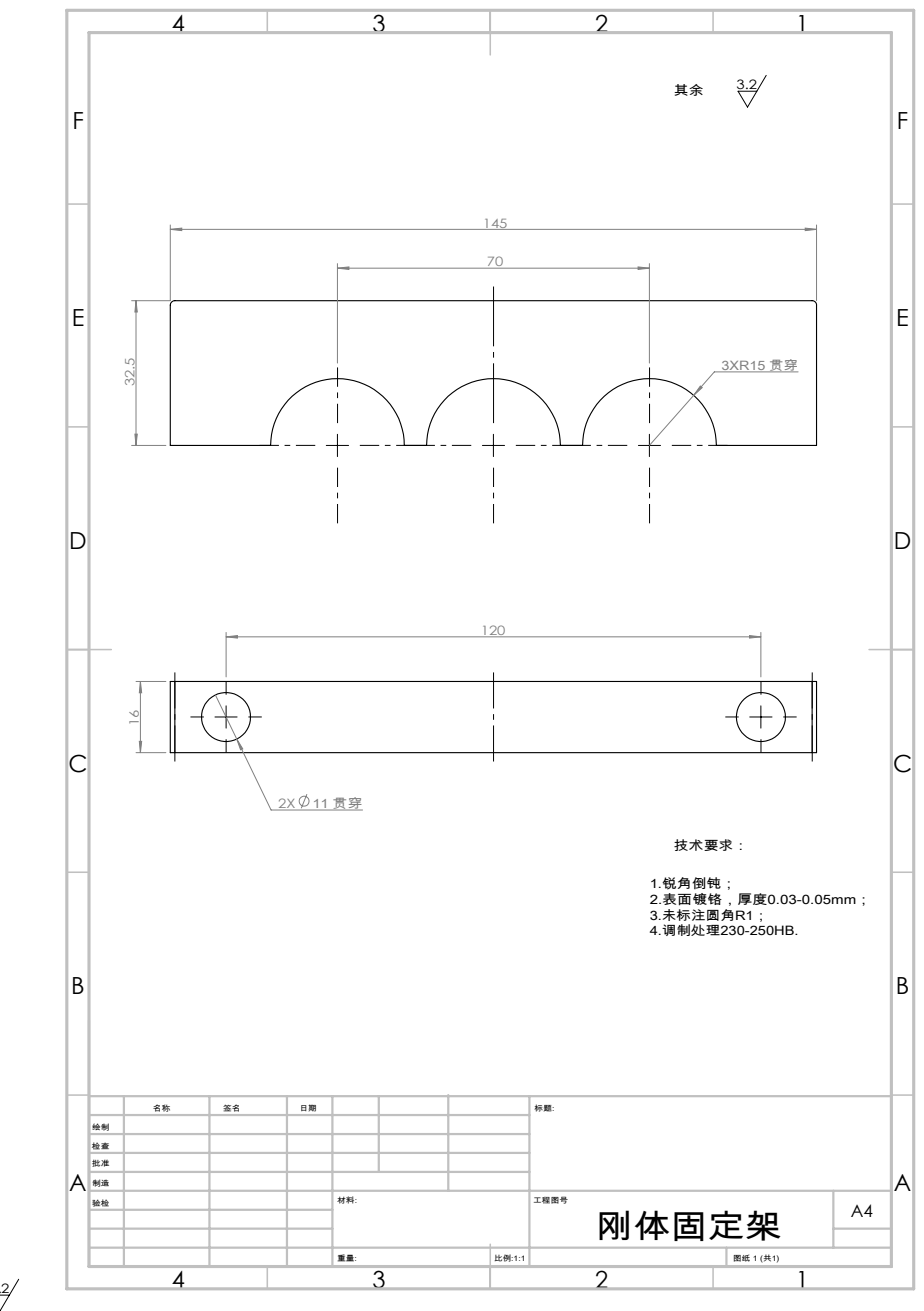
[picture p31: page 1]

绘制
检查
批准
制造
验检 | | | | 材料: | 工程图号 刚体固定架 | A4

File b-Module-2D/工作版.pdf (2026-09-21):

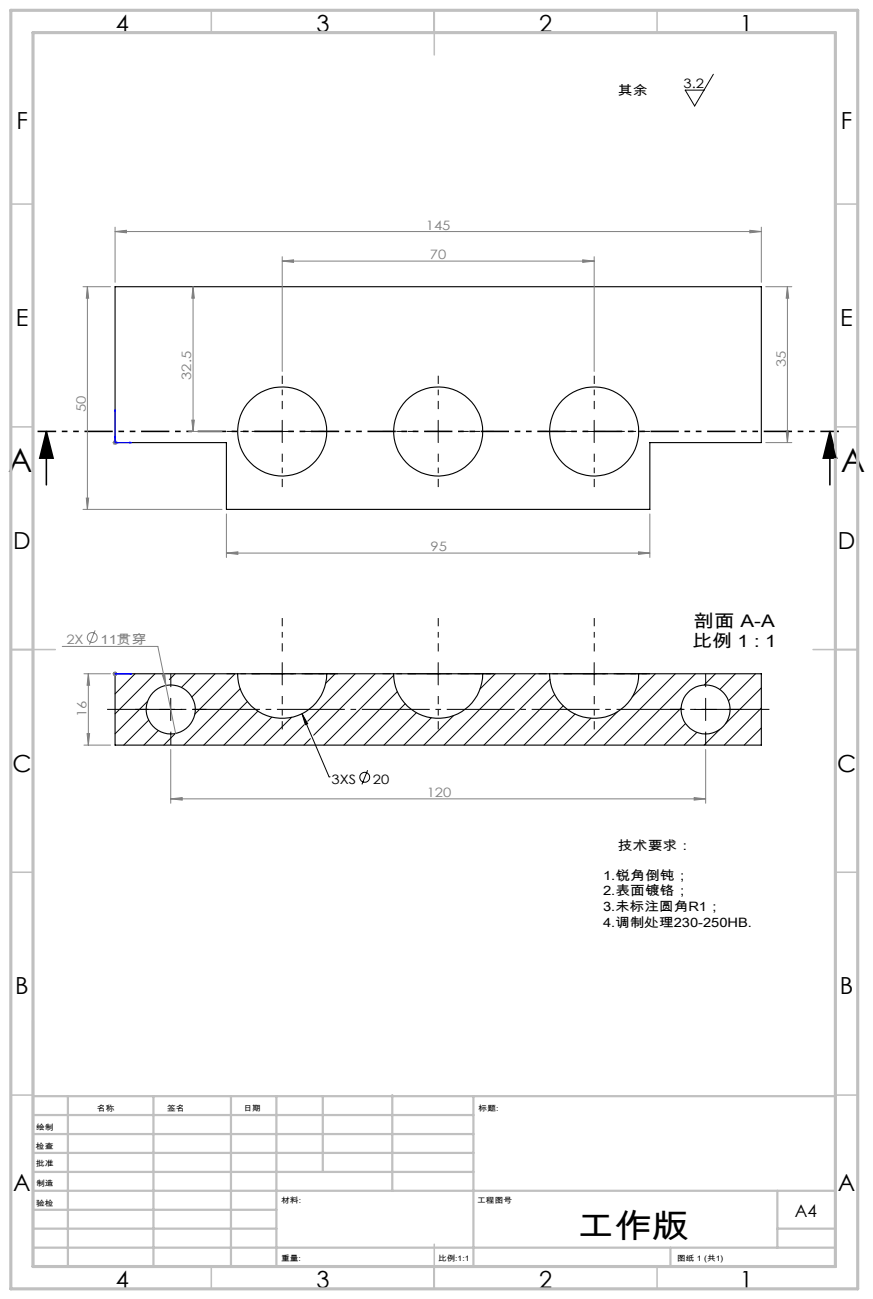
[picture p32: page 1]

绘制
检查
批准
制造
验检 | | | | 材料: | 工程图号 工作版 | A4

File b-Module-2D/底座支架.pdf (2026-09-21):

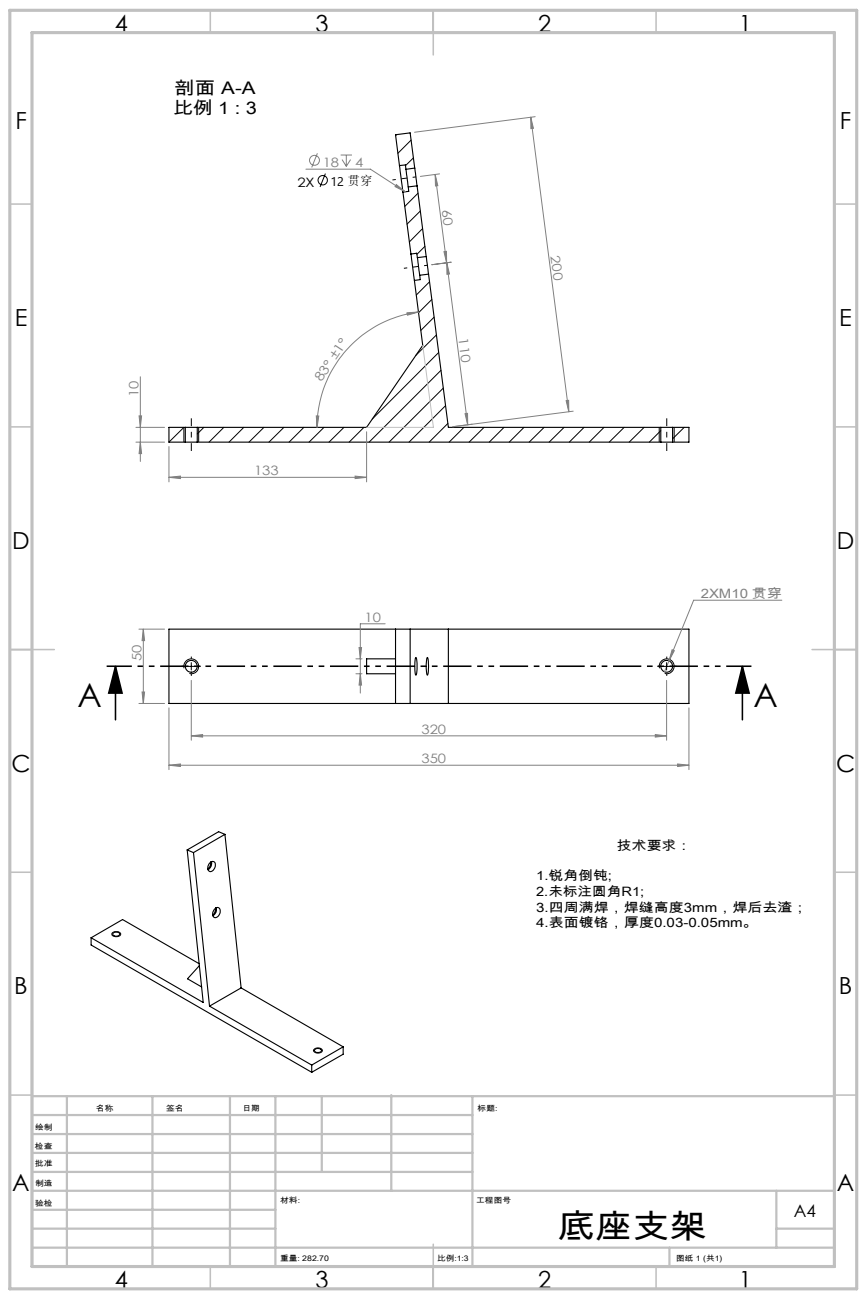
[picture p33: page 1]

绘制
检查
批准
制造
验检 | | | | 材料: | 工程图号 底座支架 | A4

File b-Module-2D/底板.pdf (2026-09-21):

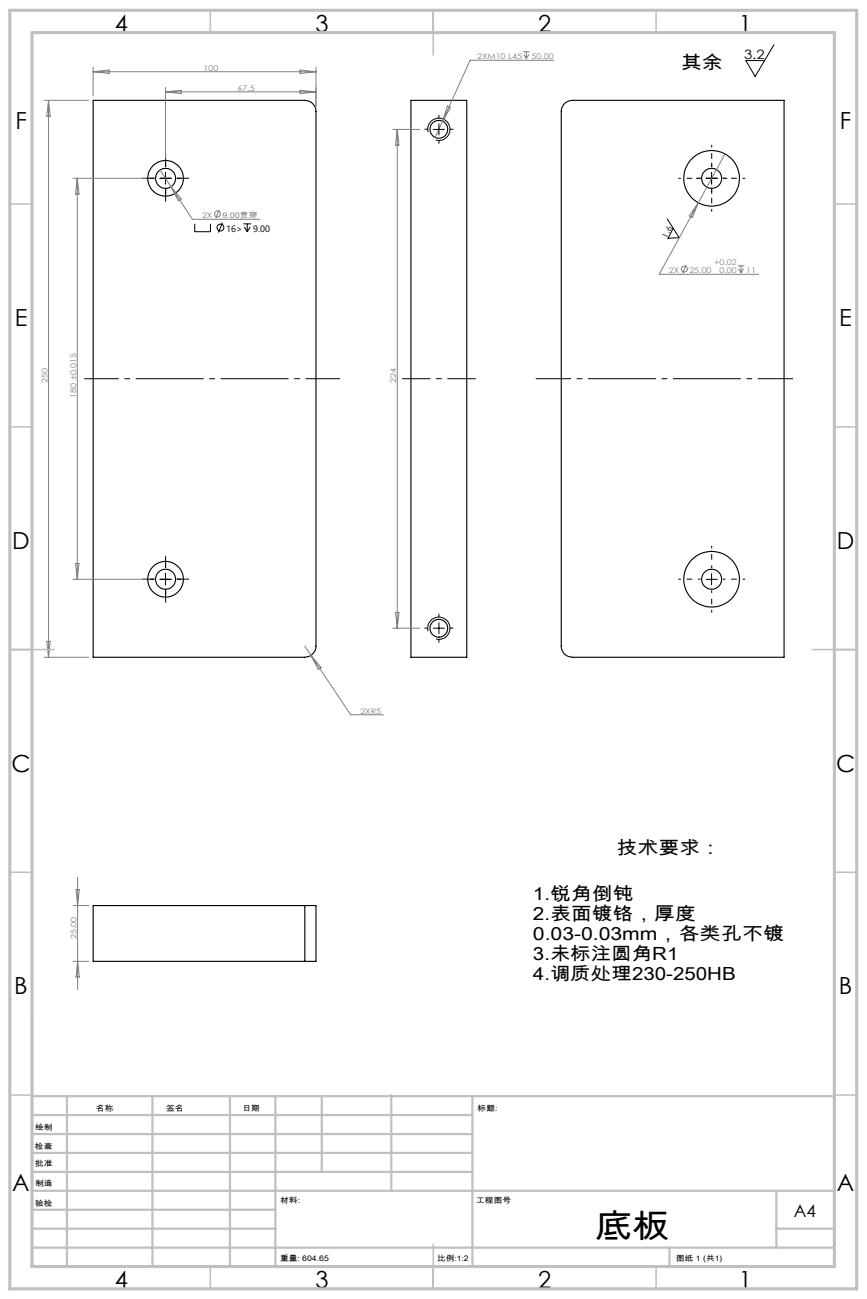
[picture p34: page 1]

绘制
检查
批准
制造
验检 | | | | 材料: | 工程图号 底板 | A4

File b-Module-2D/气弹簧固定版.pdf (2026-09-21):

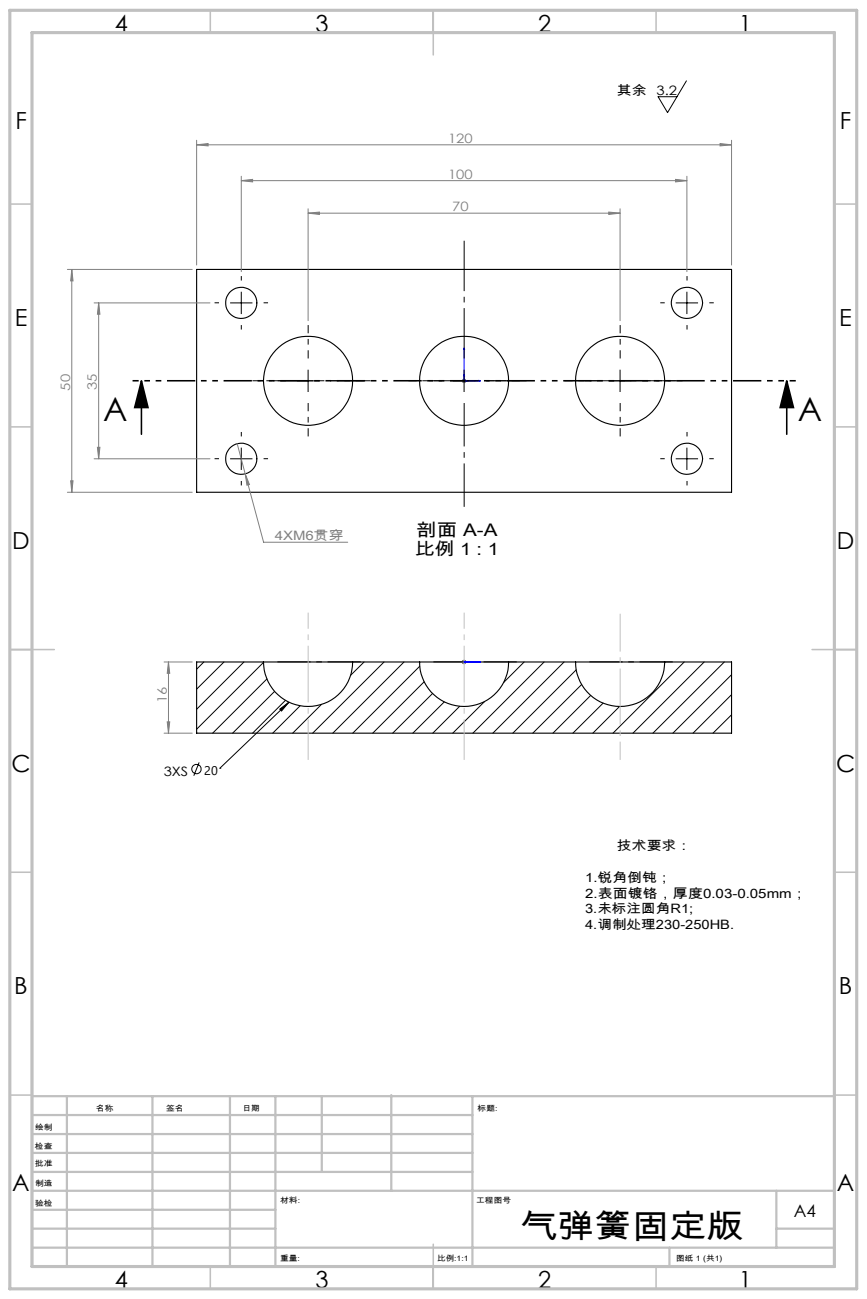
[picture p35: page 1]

绘制
检查
批准
制造
验检 | | | | 材料: | 工程图号 气弹簧固定版 | A4

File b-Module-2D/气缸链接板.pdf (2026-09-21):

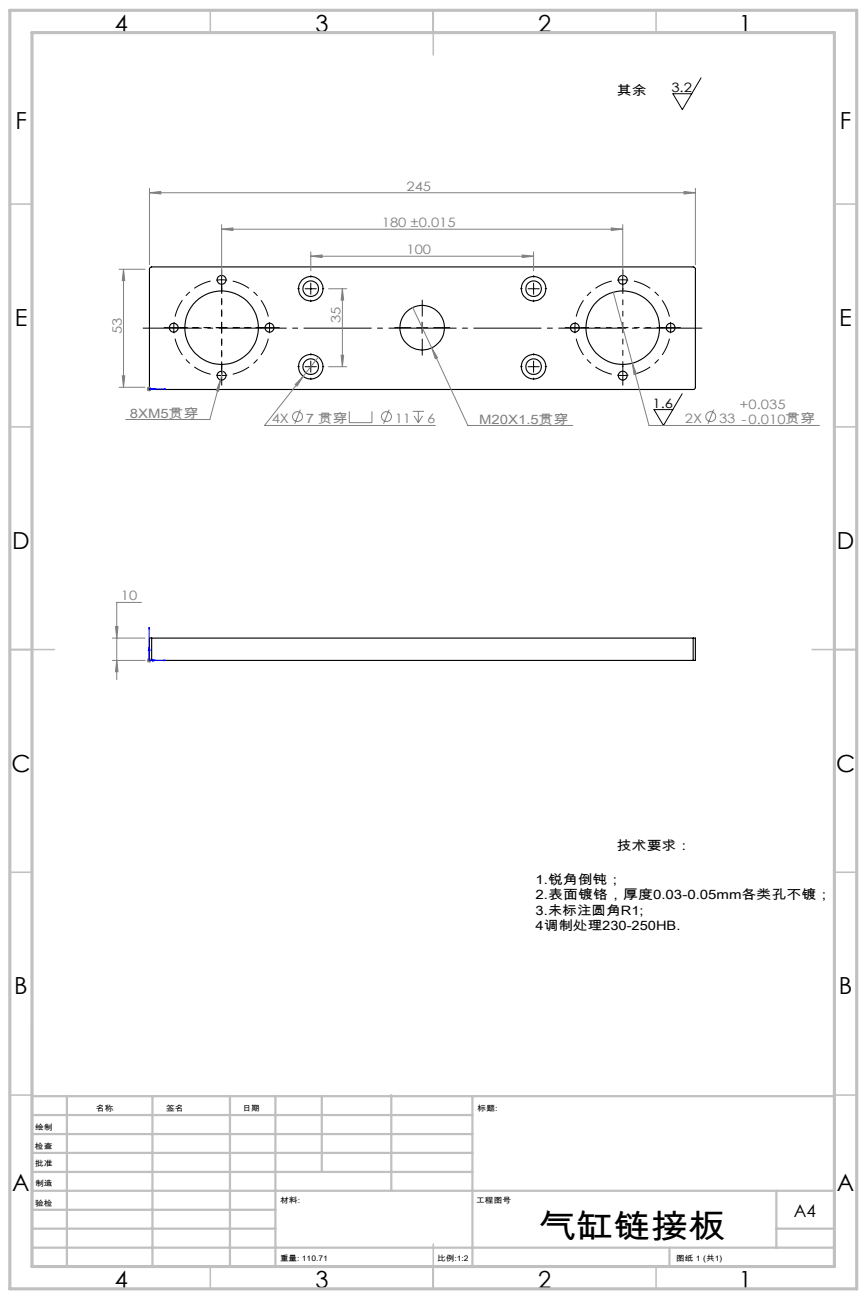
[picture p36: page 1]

绘制
检查
批准
制造
验检 | | | | 材料: | 工程图号 气缸链接板 | A4

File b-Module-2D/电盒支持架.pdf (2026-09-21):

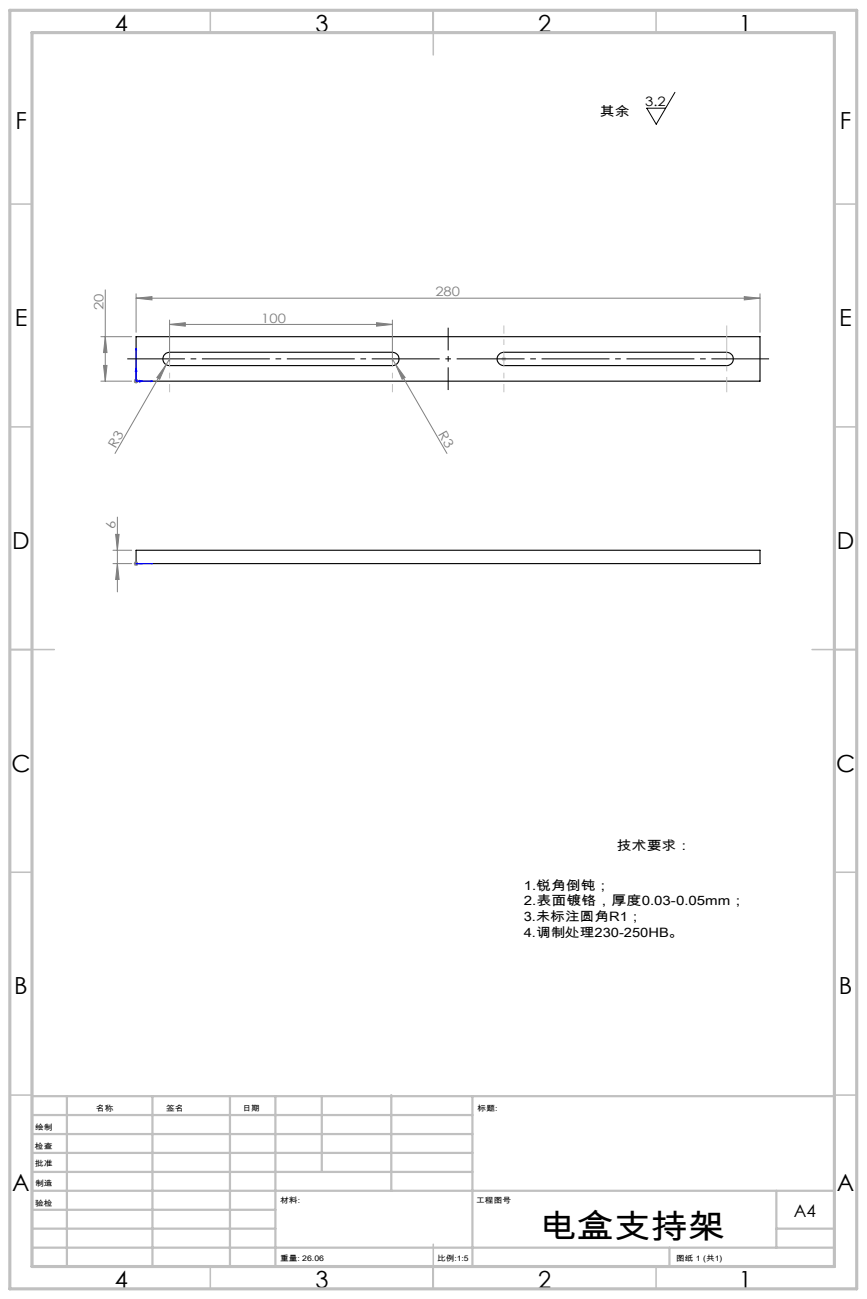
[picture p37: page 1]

绘制
检查
批准
制造
验检 | | | | 材料: | 工程图号 电盒支持架 | A4

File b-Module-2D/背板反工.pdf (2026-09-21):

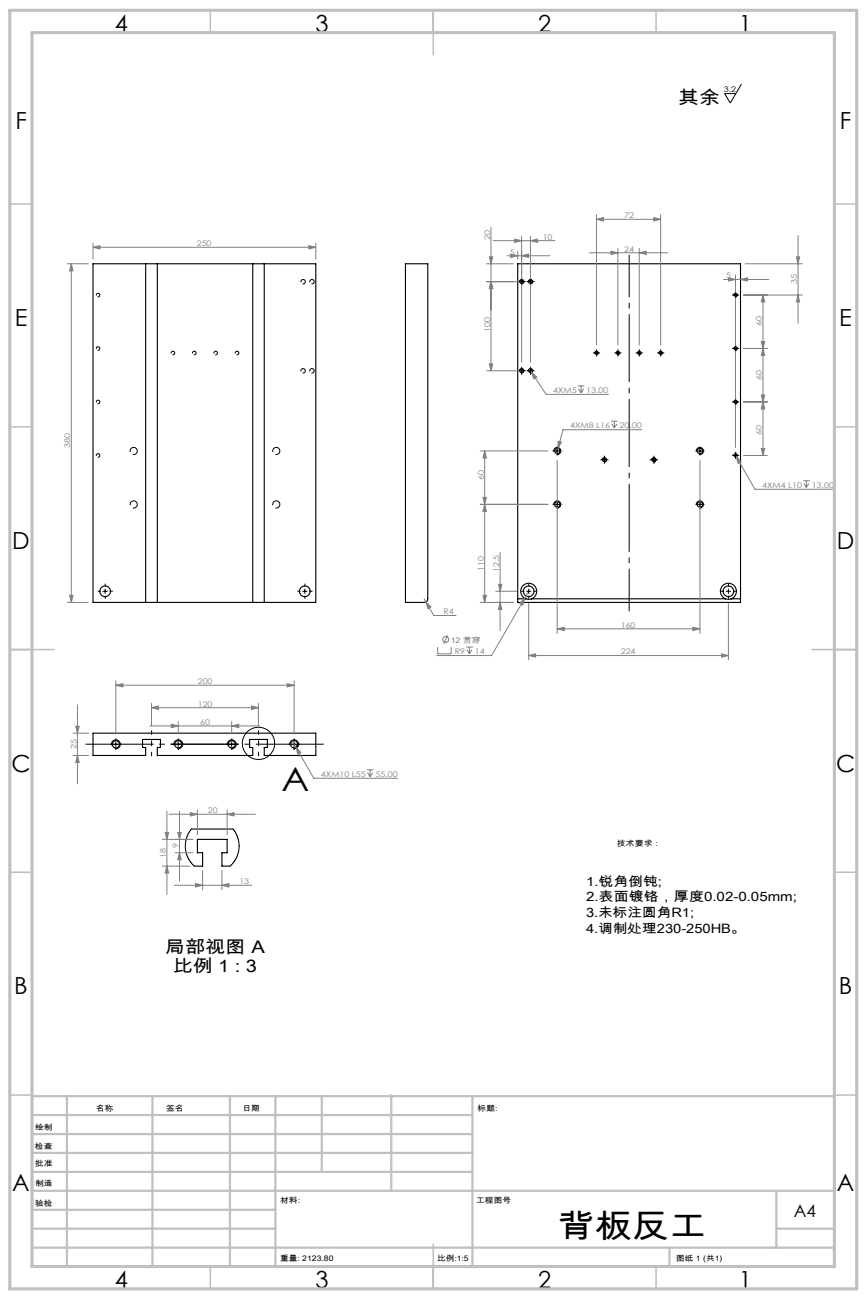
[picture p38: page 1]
局部视图 A 比例 1 : 3

绘制
检查
批准
制造
验检 | | | | 材料: | 工程图号 背板反工 | A4

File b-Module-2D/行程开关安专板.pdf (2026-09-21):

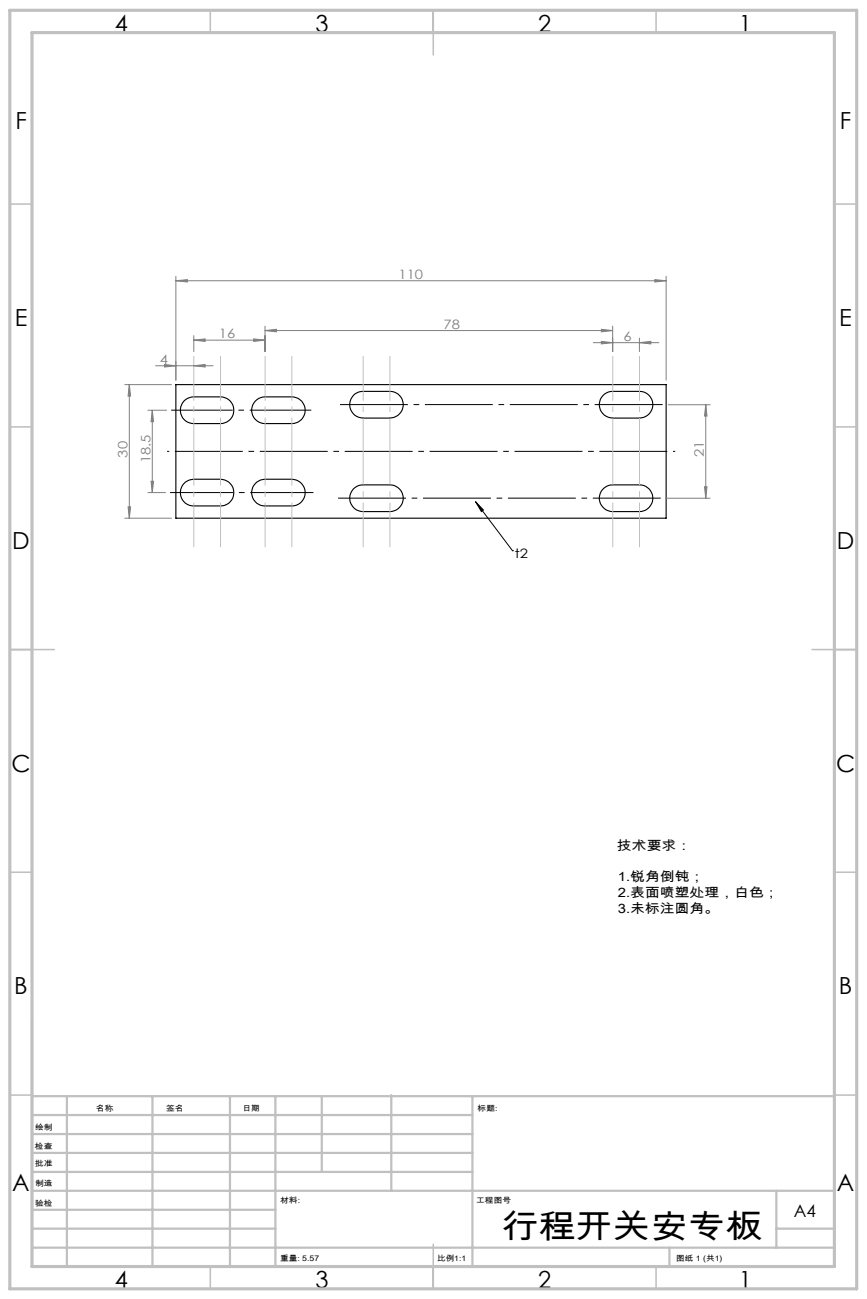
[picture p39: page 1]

绘制
检查
批准
制造
验检 | | | | 材料: | 工程图号 行程开关安专板 | A4

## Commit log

2026-05-17 feat:添加Logo
2026-05-24 feat: 把body外置
    [0-装配体.SLDASM, 0-装配体.cfg, BOM表.xlsx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]
2026-05-24 feat: 修改readme
2026-05-27 更新备份内容 - 2026-05-27 22:18
2026-05-27 更新备份内容 - 2026-05-27 22:24
2026-05-27 更新备份内容 - 2026-05-27 23:20
2026-05-28 添加Unused
    [0-装配体.SLDASM, 0-装配体.cfg, BOM表.xlsx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]
2026-05-28 修改readme
2026-05-30 添加核心内容
    [0-装配体.SLDASM, 0-装配体.cfg, 4V330C-08-Valve_Body.sldprt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]
2026-06-23 一键推送更新,将原数字标号统一改为b
    [0-装配体.cfg, 4V330C-08-Valve_Body.sldprt, 4V330C-10-Valve_Body.sldprt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]
2026-06-30 整理并修改readme
2026-07-06 一键推送更新
2026-08-12 一键推送更新 管理规则
2026-08-14 chore: 迁移到 HistoryClio 后的工作区基线
    分仓库迁移遗留在工作区的改动一次性落库，并清理模板带下来的 Unused 脚手架。
    - 删除 Unused/（3 个已入库文件，主要是 b-EPLAN 与占位 READEME）；内容仍可从历史取回。
    - 其余为迁移过程产生的工作区差异，未逐条审阅业务含义。
    本次由 Claude 代为提交，用于把分仓库后的工作树归零。
    [0-装配体.cfg, 4V330C-08-Valve_Body.sldprt, 4V330C-10-Valve_Body.sldprt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]
2026-08-17 对齐 LFS 指针规则：137 条扩展名通配 -> 185 条精确路径
    按扩展名批量套 LFS 是 11GB 占用与推送被拒的根因。现存指针逐条保留以免失效；
    新文件不再自动进 LFS，只有超过 GitHub 100MB 硬限时才由提交链路逐个征求同意。
2026-09-21 LFS 修复：185 个不足 100MB 的文件转回普通入库（第 1/1 批）
    [0-装配体.cfg, 4V330C-08-Valve_Body.sldprt, 4V330C-10-Valve_Body.sldprt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]
2026-10-10 大扫除：移出资料大文件、清理模板残留、视频压到 1080p
    为改写历史前的黄金水位线。
